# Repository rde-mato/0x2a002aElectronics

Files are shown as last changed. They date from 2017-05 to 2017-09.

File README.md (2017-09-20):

# 0x2a002aElectronics
42 Elec Project - MIDI Sequencer

The 0x2a002a is a MIDI sequencer project. It was part of a school program at 42 Paris (http://www.42.fr/) where most students have limited to none prior experience with electronics, both Firmware and Hardware.

The project spans on a 6 month period, and was carried by Remi de Matos, Théophile Vallée and Laurent Meyer. Each team chooses its own project, and makes it completely from scratch with only one hour of class per week:
* definition of technical specs: user manual, capabilities, parts, consumption.
* design of the electric schemas and routing of the PCB (using Altium software)
* building, soldering, and 3D printing for some parts
* writing asynchronous firmware, without using any external libraries except for the C standard library (including SPI, I2C, UART and chip-specific drivers)
* the only requirement is to use a PIC32 microcontroller.

The result of our project is a fully functional MIDI controller, capable of managing 16 instruments, with each of them 16 patterns of 16 beats.

Watch how Remi is happy about it: https://www.facebook.com/laurent.meyer/posts/10159690303240355

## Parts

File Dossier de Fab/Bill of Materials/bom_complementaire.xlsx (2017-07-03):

Quantity | Designator | Comment | Footprint | Description | Fabricant | RefFabricant | Fournisseur | RefFournisseur | Status
9 | Cod_1, Cod_2, Cod_3, Cod_4, Cod_5, Cod_6, Cod_7, Cod_8, Cod_9 | Cod |  |  | N/A | N/A | N/A | N/A | N/A
1 | P IN | MIDI IN Opt | MIDI | Header, 3-Pin | N/A | N/A | N/A | N/A | N/A
24 | S1_1, S1_2, S2_1, S2_2, S3_1, S3_2, S4_1, S4_2, S5_1, S5_2, S6_1, S6_2, S7_1, S7_2, S8_1, S8_2, S9_1, S9_2, S10_1, S10_2, S11_1, S11_2, S12_1, S12_2 | SW-PB | PAD | Switch | N/A | N/A | N/A | N/A | N/A
1 | P2 | Program / Debug | HDR1X6 | Header, 6-Pin | MOLEX | 22-27-2061 | Farnell | 9731172 | a commander
1 | RP1 | 220 | 3313J-1 | Potentiometer | BOURNS | 3313J-1-221E | Farnell | 2329336 | a commander
1 | P1 | MIDI Out | MIDI | Header, 3-Pin | NEUTRIK | NYS325 | Farnell | 1204611 | a commander
1 | P0 | Power Input | PWR | Header, 2-Pin | SWITCHCRAFT | 712A | Farnell | 1608729 | a commander
1 |  |  |  | Ecrou M3 x100 | DURATOOL | M3- HFA2-S100- | Farnell | 1420788 | a commander
1 |  |  |  | Vis M3 x50 | DURATOOL | D01434 | Farnell | 2444344 | a commander
1 |  |  |  | Vis Fraise M3 x100 | DURATOOL | M310 KRSTMCZ100- | Farnell | 1420398 | a commander
10 |  |  |  | Entretoise Nylon M3 25mm | ETTINGER | 5.30.325 | Farnell | 1336159 | a commander
6 |  |  |  | Entretoise Nylon M3 34mm | DURATOOL | D01492 | Farnell | 1733423 | a commander
14 | C2, C5, C7, C10, C22_MCP1, C22_MCP2, C32, C42, C92, C102, C104, C108, C110, C111 | 100nF | capa 1206 | Capacitor | MULTICOMP | MC1206B104K500CT | Farnell | 1759361 | pas commande ? - available EUR
14 | C3, C8, C21_MCP1, C21_MCP2, C31, C33, C34, C35, C36, C41, C91, C101, C103, C109 | 10uF | capa 1206 | Capacitor | MULTICOMP | MC1206X106K160CT | Farnell | 2320922 | pas commande ? - available EUR
2 | C105, C106 | 22pF | capa 1206 | Capacitor | MULTICOMP | MC1206N220J101CT | Farnell | 2320864 | pas commande ? - available EUR
1 | R1 | 560 | RES 1206 | Resistor | MULTICOMP | MC0125W12065560R | Farnell | 9337490 | pas commande ? - available EUR
1 | R3 | 330 | RES 1206 | Resistor | MULTICOMP | MC0125W12065330R | Farnell | 9337326 | pas commande ? - available EUR
33 | R61, R62, R63, R64, R65, R66, R67, R68, R69, R501_1, R501_2, R502_1, R502_2, R503_1, R503_2, R504_1, R504_2, R505_1, R505_2, R506_1, R506_2, R507_1, R507_2, R508_1, R508_2, R509_1, R509_2, R510_1, R510_2, R511_1, R511_2, R512_1, R512_2 | 39k | RES 1206 | Resistor | MULTICOMP | MC0125W1206539K | Farnell | 9337407 | pas commande ? - available EUR
4 | R2, R4, R101, R102 | 220 | RES 1206 | Resistor | MULTICOMP | MC0125W12065220R | Farnell | 9337210 | pas commande ? - available EUR
43 | R31, R32, R41, R42, R43, R44, R71_1, R71_2, R71_3, R71_4, R71_5, R71_6, R71_7, R71_8, R71_9, R72_1, R72_2, R72_3, R72_4, R72_5, R72_6, R72_7, R72_8, R72_9, R73_1, R73_2, R73_3, R73_4, R73_5, R73_6, R73_7, R73_8, R73_9, R74_1, R74_2, R74_3, R74_4, R74_5, R74_6, R74_7, R74_8, R74_9, R103 | 10K | RES 1206 | Resistor | MULTICOMP | MC0125W1206510K | Farnell | 9337016 | pas commande ? - available EUR
18 | C71_1, C71_2, C71_3, C71_4, C71_5, C71_6, C71_7, C71_8, C71_9, C72_1, C72_2, C72_3, C72_4, C72_5, C72_6, C72_7, C72_8, C72_9 | 10nF | capa 1206 | Capacitor | MULTICOMP | MC1206B103M631CT | Farnell | 1709222 | pas commande ? - available USA
3 | D51_1, D51_2, D61 | BAV20W | Diode SOD-123 | Default Diode | MICRO COMMERCIAL COMPONENTS | BAV20W-TP | Farnell | 1924304 | a commander remplacement 1902417
3 | D51_1, D51_2, D61 | BAV20W | Diode SOD-123 | Default Diode | DIODES INC. | BAV20W | Farnell | 1902417 | annule - attente livraison
32 | D1_1, D1_2, D1_3, D1_4, D2_1, D2_2, D2_3, D2_4, D3_1, D3_2, D3_3, D3_4, D4_1, D4_2, D4_3, D4_4, D5_1, D5_2, D5_3, D5_4, D6_1, D6_2, D6_3, D6_4, D7_1, D7_2, D7_3, D7_4, D8_1, D8_2, D8_3, D8_4 | LED | LED-3mm | LED, ROUND, 5MM, BLUE | CREE | C503B-BCN-CV0Z0462 | Farnell | 2414443 | pas commande ? - available USA
1 | P3 | SDAMB-01215BT00 |  |  | MULTICOMP | SDAMB-01215BT00 | Farnell | 9186140 | recu
1 | RP2 | 100 | 3313J-1 | Potentiometer | BOURNS | 3313J-1-101E | Farnell | 2321829 | recu
1 | RP91 | 10K | 3313J-1 | Potentiometer | BOURNS | 3313J-1-103E | Farnell | 1612588 | recu
1 | C107 | 10uF | CAPA 1206 POL | Polarized Capacitor (Radial) | KEMET | T491A106K010AT | Farnell | 1457413 | recu
2 | C1, C6 | 470uF | CAPA PANA SIZE D* | Polarized Capacitor (Radial) | PANASONIC | EEEFTA471XAP | Farnell | 2065963 | recu
2 | C4, C9 | 100uF | CAPA PANA SIZE D* | Polarized Capacitor (Radial) | PANASONIC | EEE1AA101SP | Farnell | 2326098 | recu
2 | U7, U8 | LM317 | D2PAK |  | ON SEMICONDUCTOR | LM317D2T-TR | Farnell | 1564300 | recu
4 | D2, D3, D6, D7 | GF1B | DO-214AC(SMA) | Default Diode | FAIRCHILD SEMICONDUCTOR | GF1B | Farnell | 1467477 | recu
1 | Y1 | 8Mhz | HC49/4H SMX CRYSTAL | Crystal Oscillator | FOX ELECTRONICS | FOXSDLF/080-20 | Farnell | 2063972 | recu
1 | U4 | HT16K33 | HT16K33 SOP |  | Holtek | HT16K33-28SOP | AliExpress | N/A | recu
1 | U6 | LCD-128H064A | LCD-128H064A |  | N/A | KS0108 | Adafruit | 188 | recu
2 | U3_MCP1, U3_MCP2 | MCP23S17 | MCP23S17-E/SO |  | Microchip | MCP23S17-E/SO | Farnell | 1332093 | recu
1 | U2 | NL37WZ07USG | NL37WZ07USG |  | ON SEMICONDUCTOR | NL37WZ07USG | Farnell | 2534491 | recu
1 | Cod_9 | Switch | PEC11R-4xxxF-Sxxxx |  | BOURNS | PEC11R-4220F-S0024 | Farnell | 2663527 | recu
8 | Cod_1, Cod_2, Cod_3, Cod_4, Cod_5, Cod_6, Cod_7, Cod_8 | Switch | PEC11R-4xxxF-Sxxxx |  | BOURNS | PEC11R-4020F-S0024 | Farnell | 2663519 | recu
1 | U1 | PIC32MX150F128B | PIC32MX150F128B-I/SO |  | Microchip | PIC32MX150F128B-I/SO | Farnell | 2313766 | recu
3 | D1, D4, D5 | RS3B+ | SMC Vishay | Default Diode | MULTICOMP | RS3B+ | Farnell | 2675034RL | recu
1 | U5 | SST25VF020B | SST25VF020B |  | MICROCHIP | SST25VF020B-80-4I-SAE | Farnell | 1829953 | recu

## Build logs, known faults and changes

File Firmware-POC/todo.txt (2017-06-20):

- cleaner le code a perimetre egal
- faire un systeme de definition de keys
- faire un fichier avec toutes les variables globales ?
- mettre en place le mode rec
- voir si on ne peut pas simplifier le SPI en ne faisant que du 8 bits
- optimiser l'affichage de l'écran (changer uniquement les chars qui changent)
- gerer le multislave du spi

determiner des boutons de controle (pas dans le chenillard) et les actions associees
mettre des patterns en memoire
faire marcher le lcd
garder en memoire les valeurs des parametres
comment sauvegarder d'une session a l'autre meme en cas de machine eteinte a la main ?
comment faire durer un message a l'écran pendant x secondes seulement ? il nous faut un timer disponible. Ou faire une fonction de timer generique, qui prend un callback. Ca permettrait de gerer aussi les appuis longs.
dedoubler le charset pour faire la diapositive de chaque caractere
determiner des ecrans type pour chaque situation, qui prennent en parametre les variables globales : ex : un encodeur tourne etc
par consequent, bien s'assurer qu'un refresh de l'écran est instant, et qu'en plus il ne bouffe pas toutes les ressources du PIC ce qui serait bloquant

SPI
besoin de faire un buffer
comment mettre en place un systeme de priorité dans le buffer ?
d'ailleurs qu'est ce qui est prioritaire pour le spi ? ecran ou encodeurs ou ???
gerer l'envoi des données avec un buffer par slave ?
possible de gérer les 32 en 4 fois 8 bits ? quel impact ?
besoin de gerer : un mcp pour lcd, un mcp pour encodeurs, une flash, une sd

Variables :
- note courante (reinitialisee a chaque demarrage de machine). Note au sein de l'octave, donc la valeur finale entre 12 et 108 peut etre recuperee facilement
- velocite courante
- octave courant
- instrument courant
- boucle courante
- tempo
- 8 parametres additionnels par instrument
- play/pause
- instruments actifs => u16
- mode courant : play / live

ORDRE DE LA MEMOIRE
Instrument
Pattern
Beat
Notes et velocites

BESOINS EN TIMERS
- bpm
- appui long
- ecrans temporaires

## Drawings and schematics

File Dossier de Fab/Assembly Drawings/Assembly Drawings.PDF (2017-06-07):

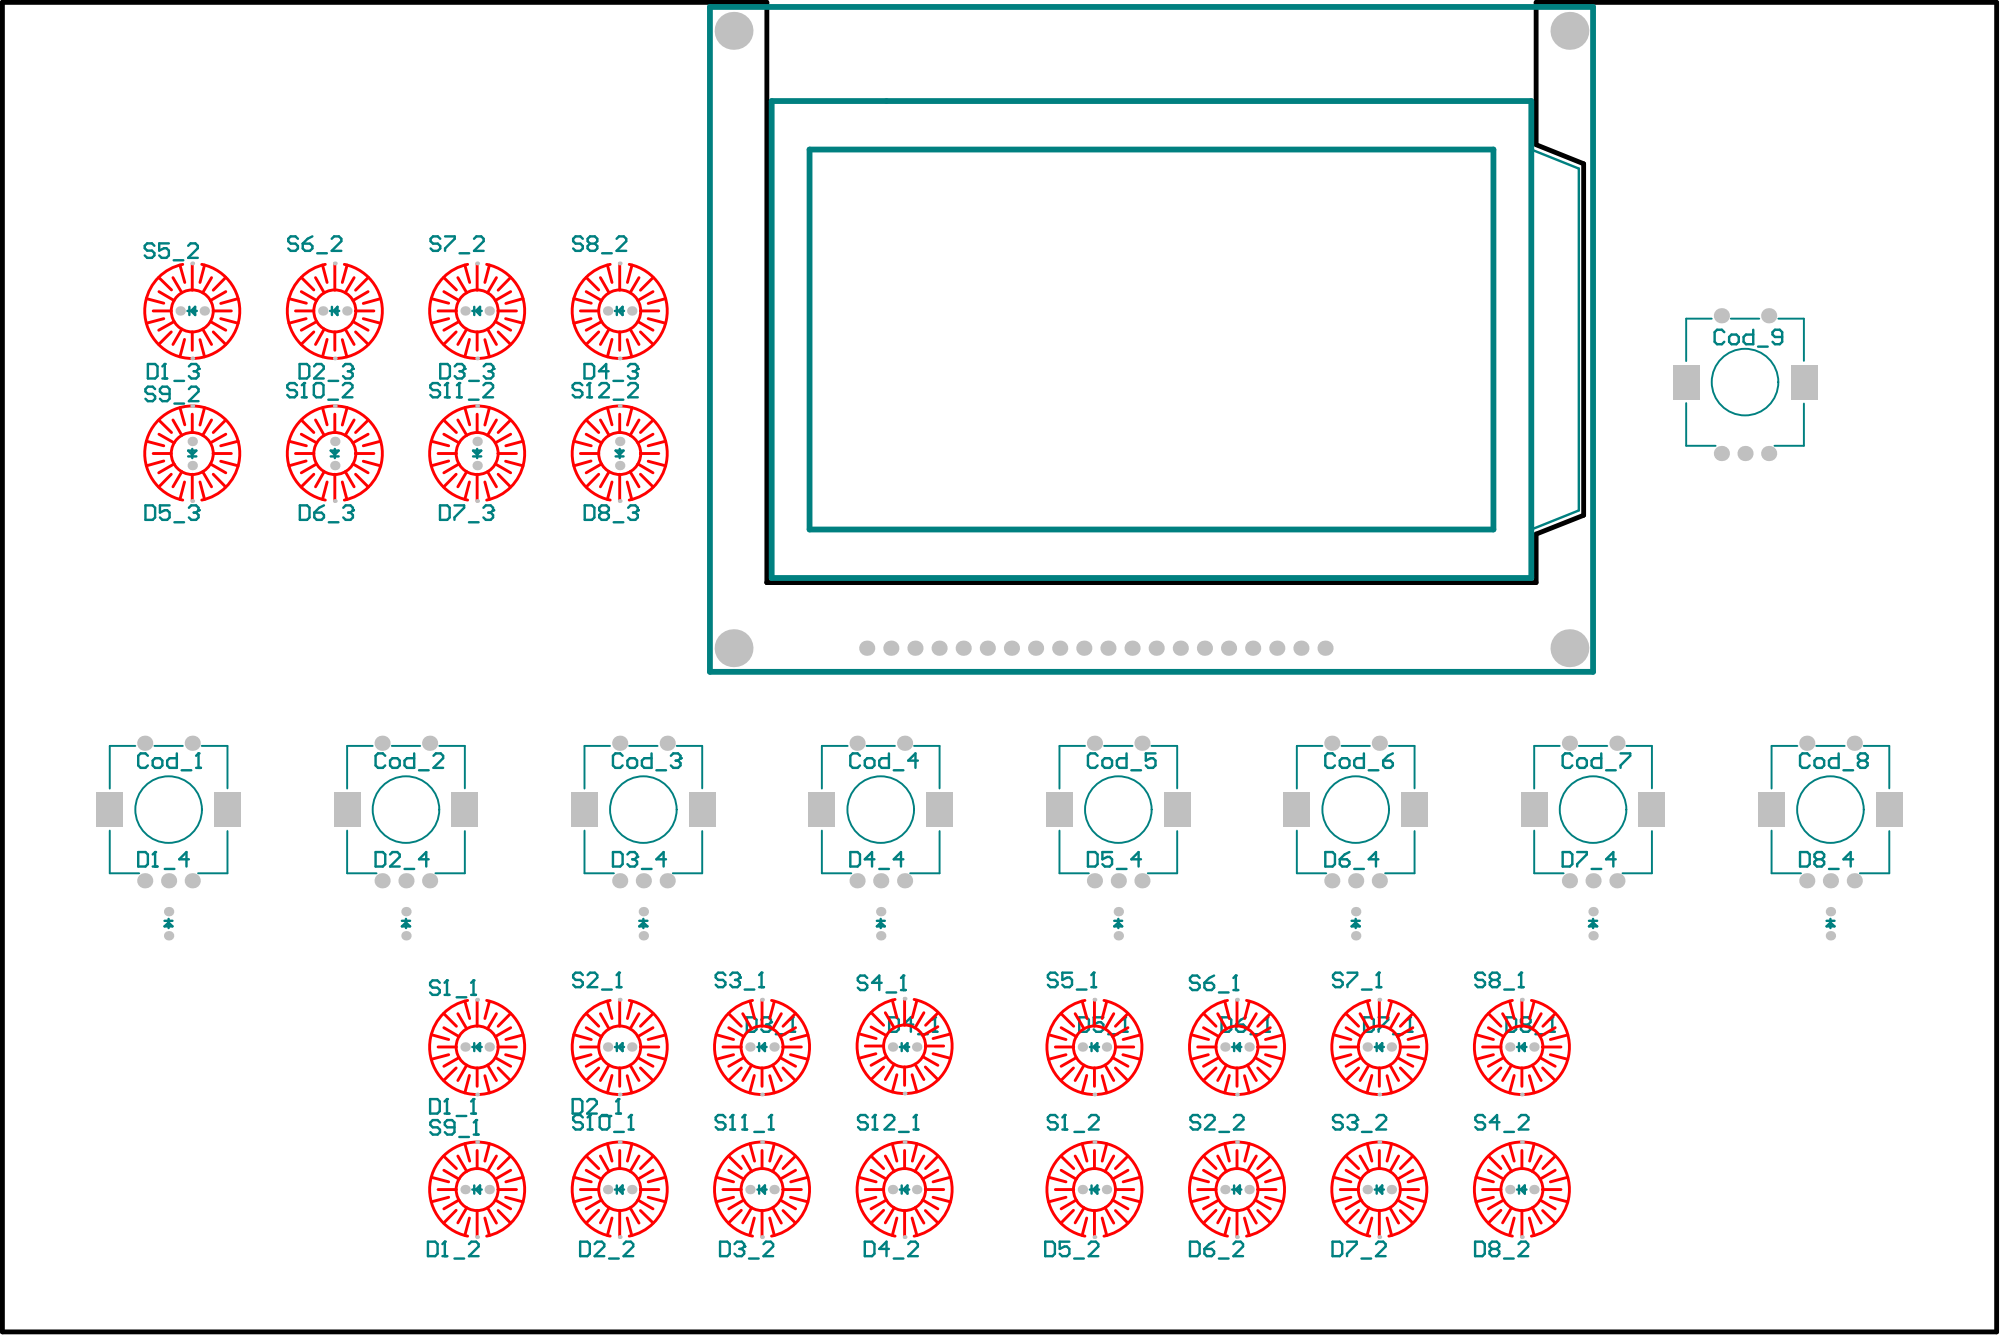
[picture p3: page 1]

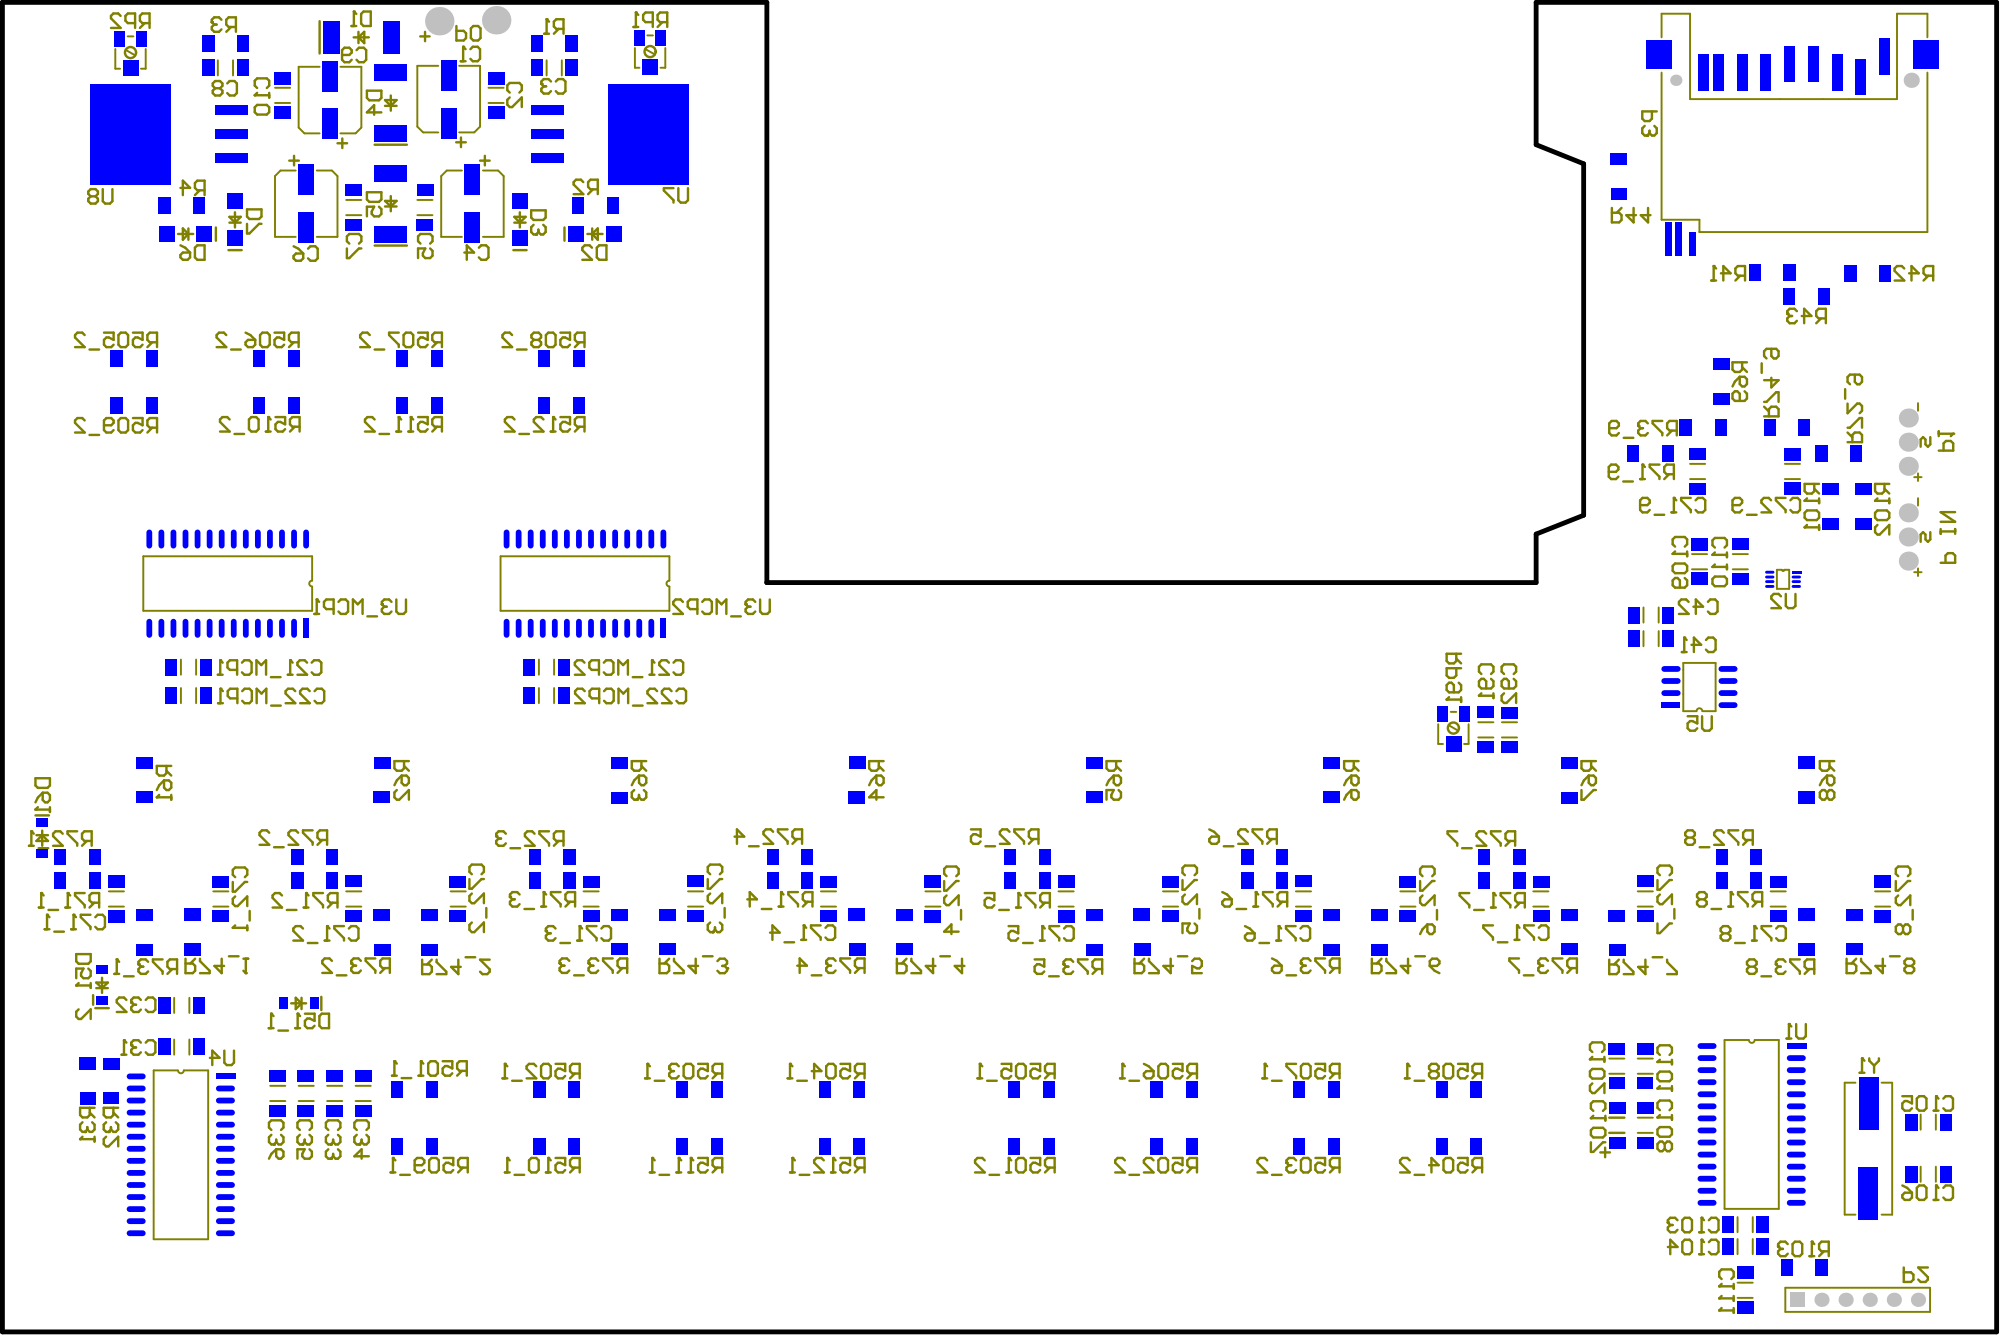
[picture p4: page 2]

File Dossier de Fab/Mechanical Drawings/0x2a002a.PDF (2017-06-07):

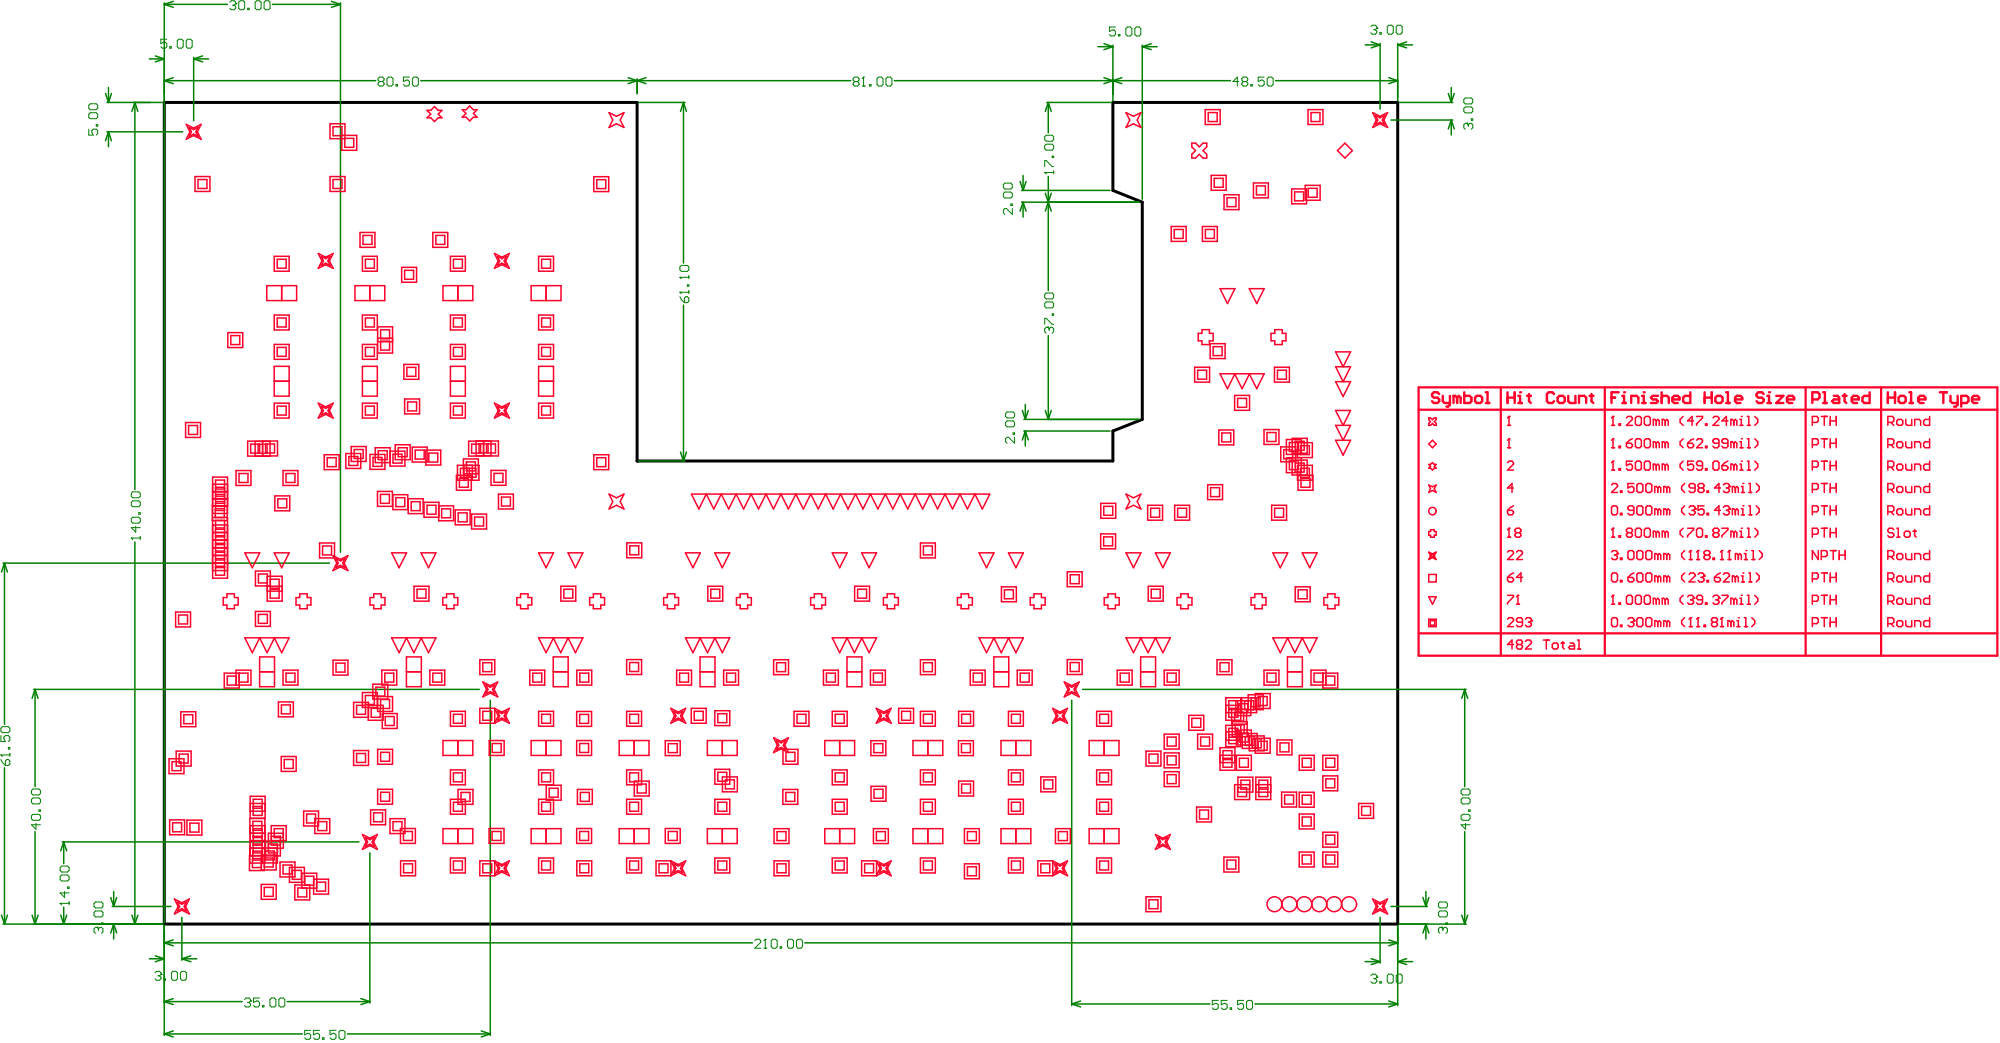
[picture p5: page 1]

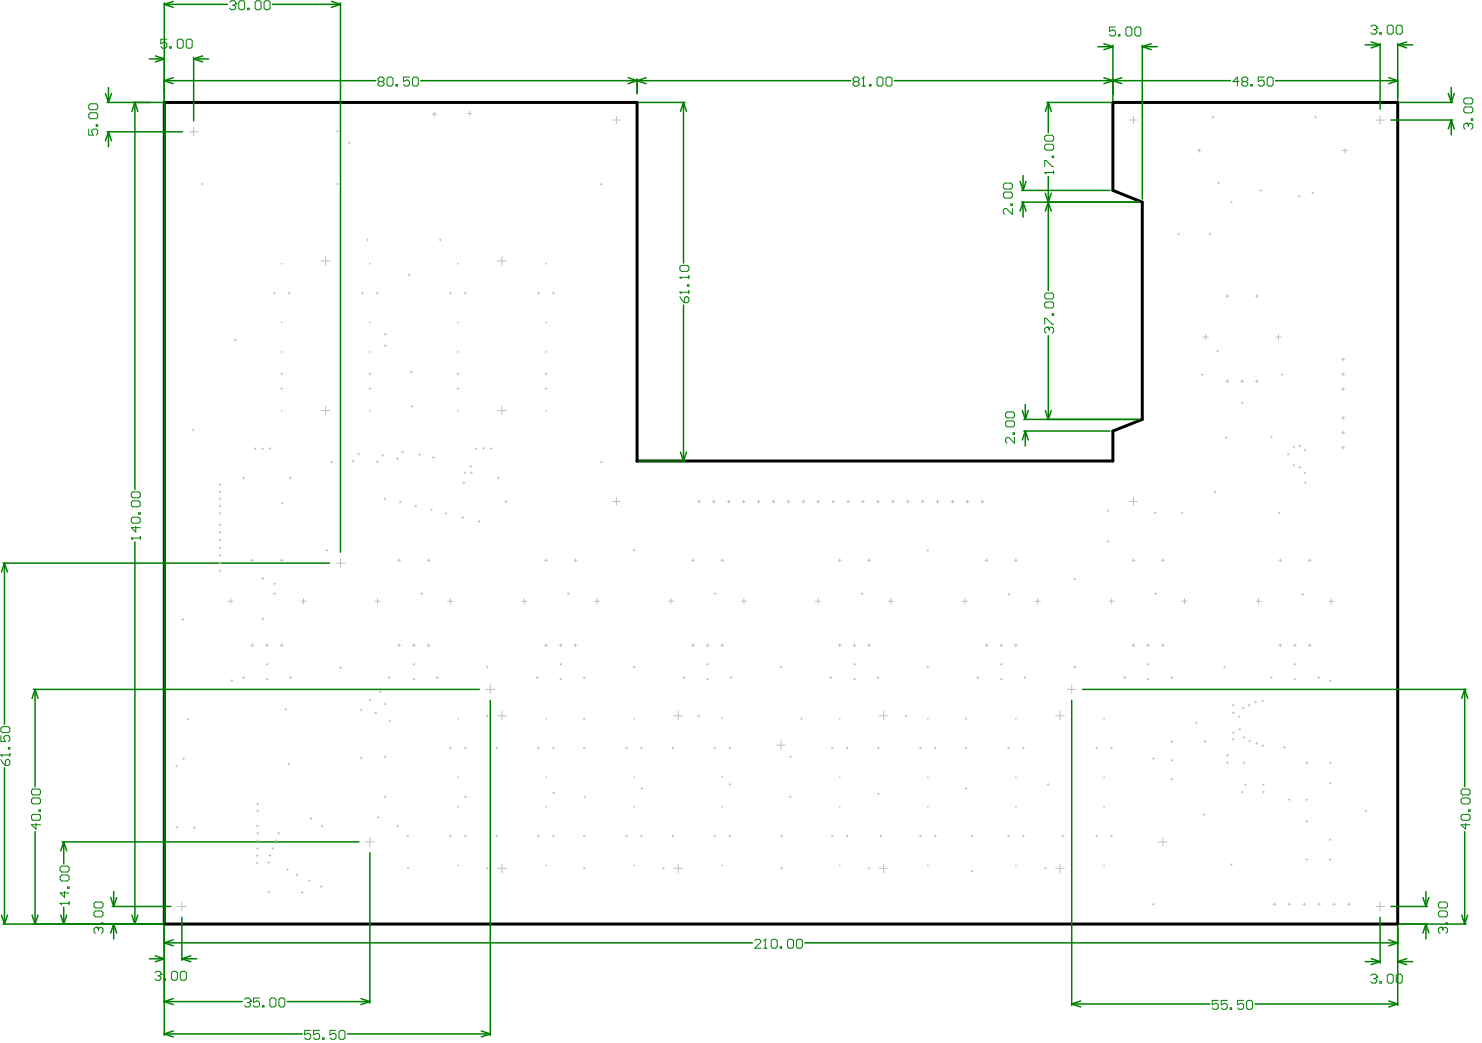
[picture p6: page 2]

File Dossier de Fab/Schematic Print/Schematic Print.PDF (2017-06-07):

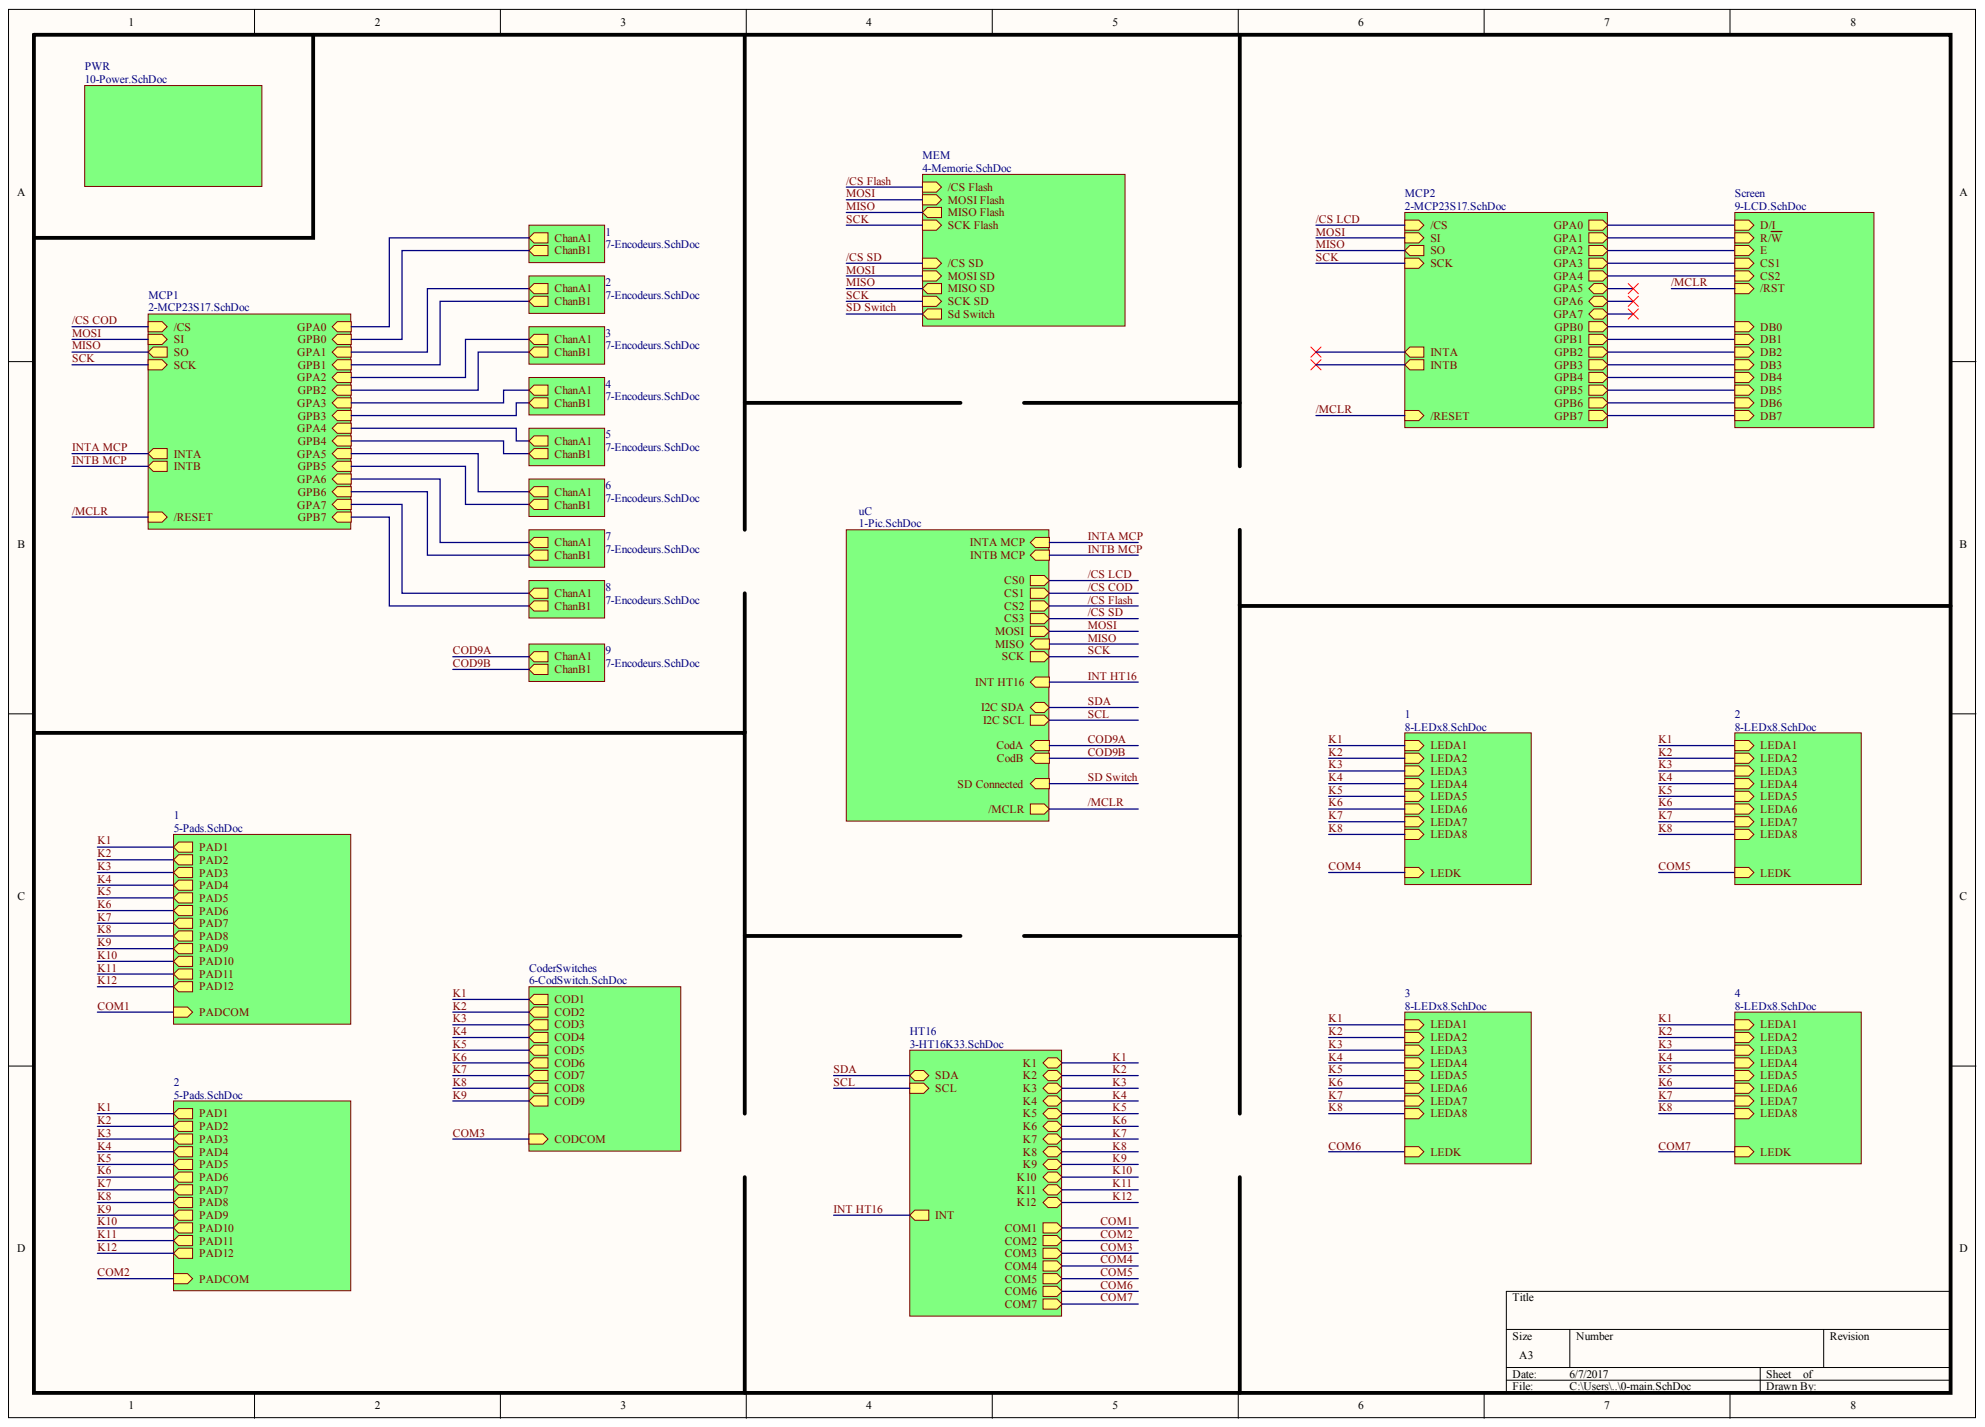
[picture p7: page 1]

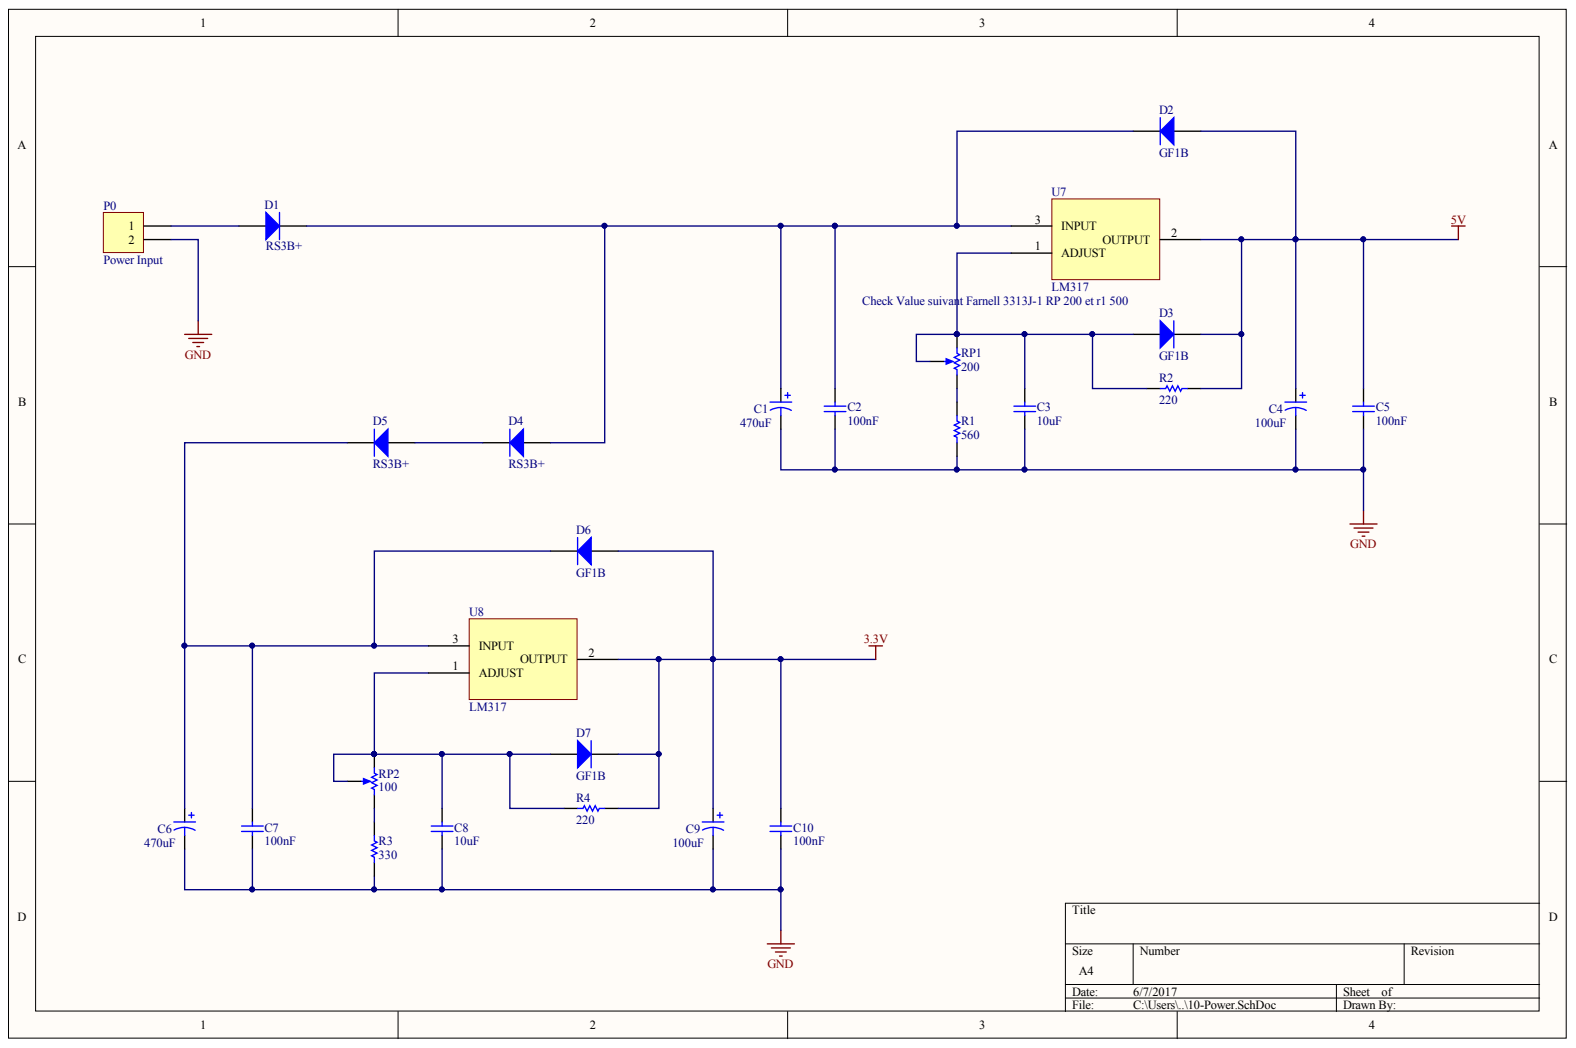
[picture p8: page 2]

Check Value suivant Farnell 3313J-1 RP 200 et r1 500

Size A4 | Number | Revision

Date: 6/7/2017 | Sheet of
File: C:\Users\..\10-Power.SchDoc | Drawn By:

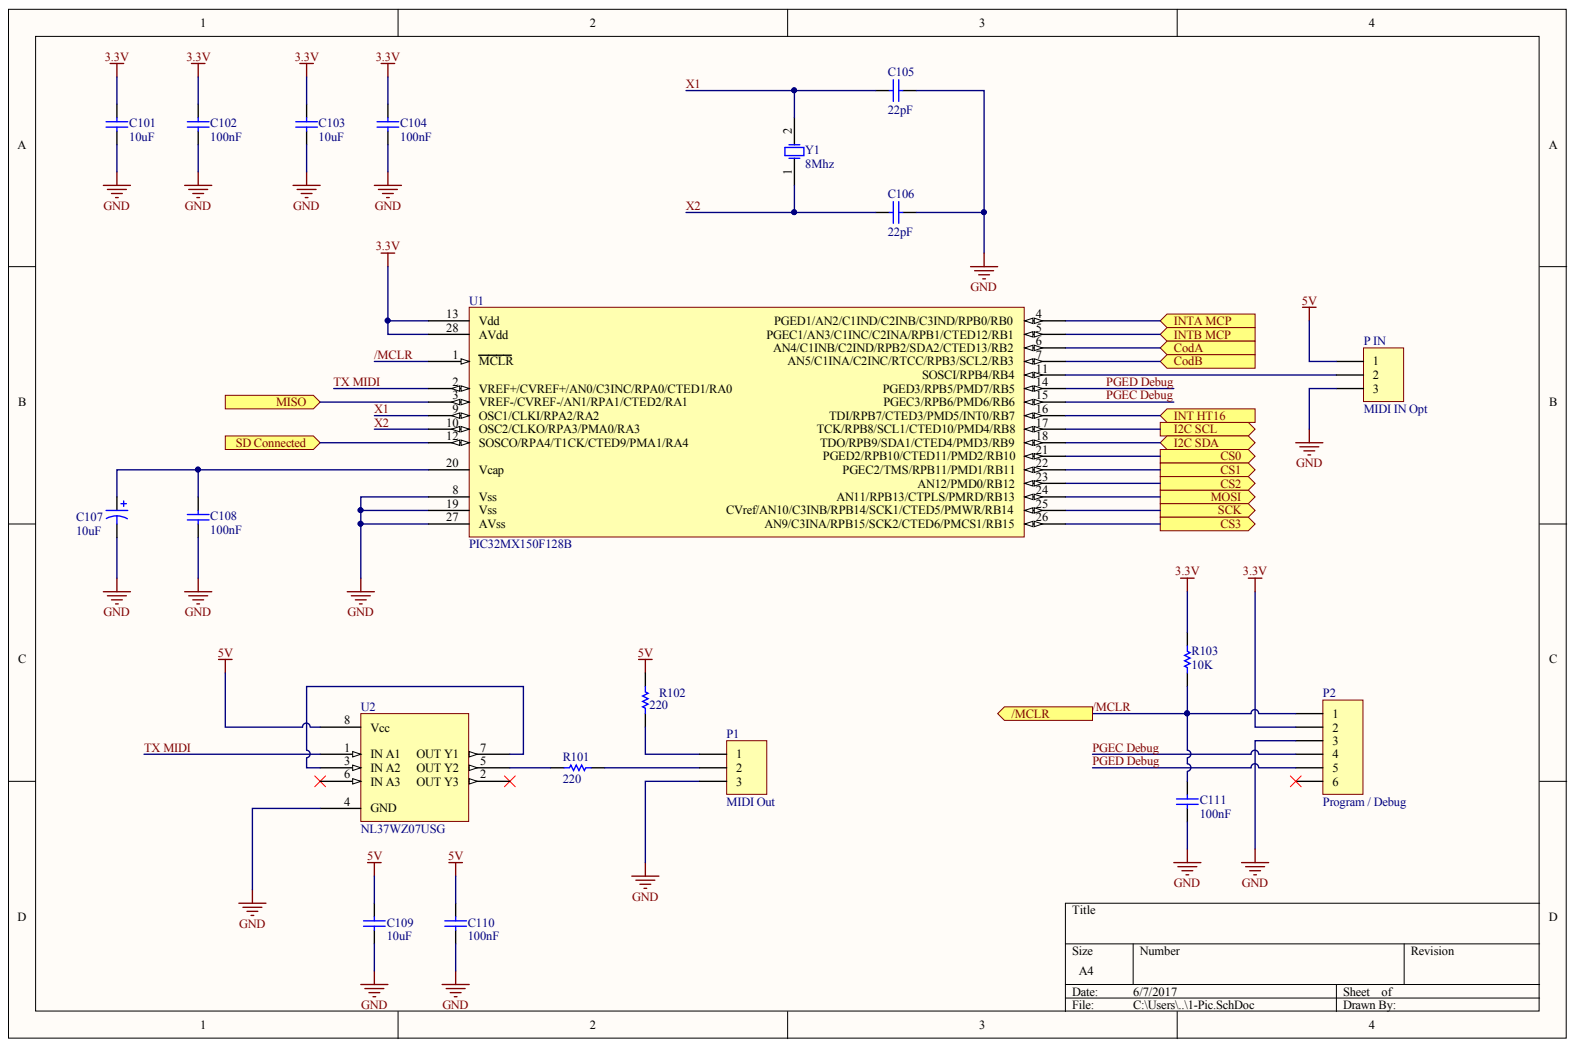
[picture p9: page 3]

Vss 8

AVss 27

Size A4 | Number | Revision

Date: 6/7/2017 | Sheet of
File: C:\Users\..\1-Pic.SchDoc | Drawn By:

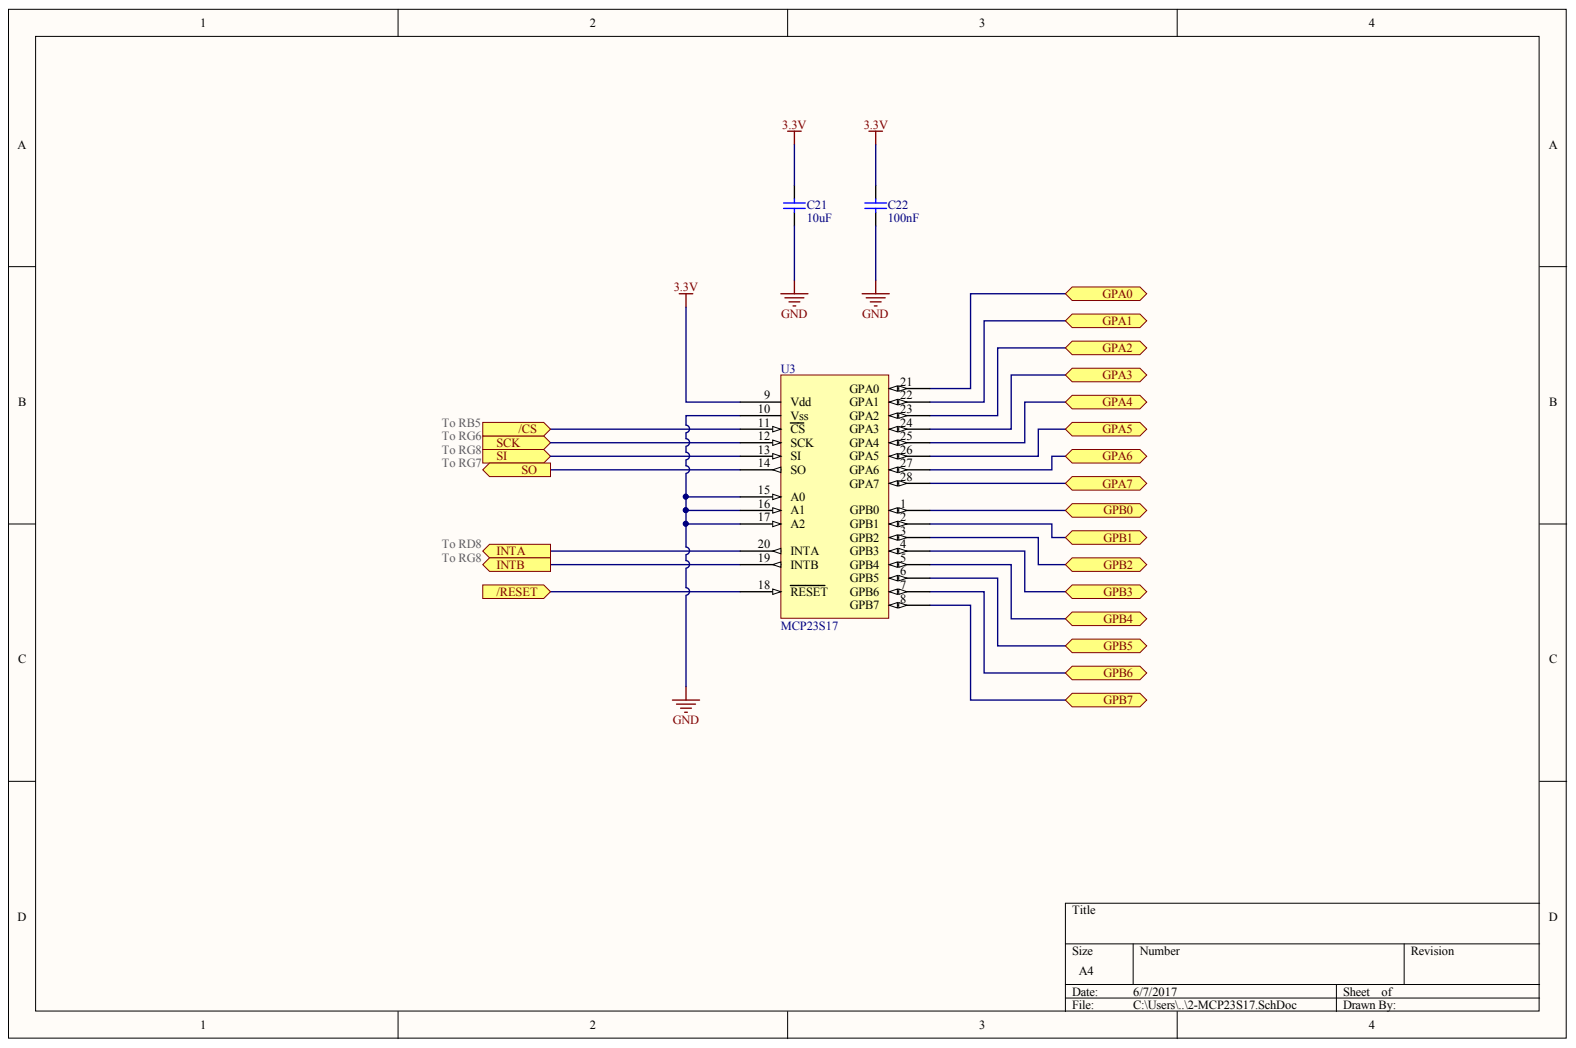
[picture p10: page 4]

Numbe r | R evision

: 6/7/2017 | She et of
File : C:\Use rs\. .\2-MC P23S17. S chDoc | D r awn By:

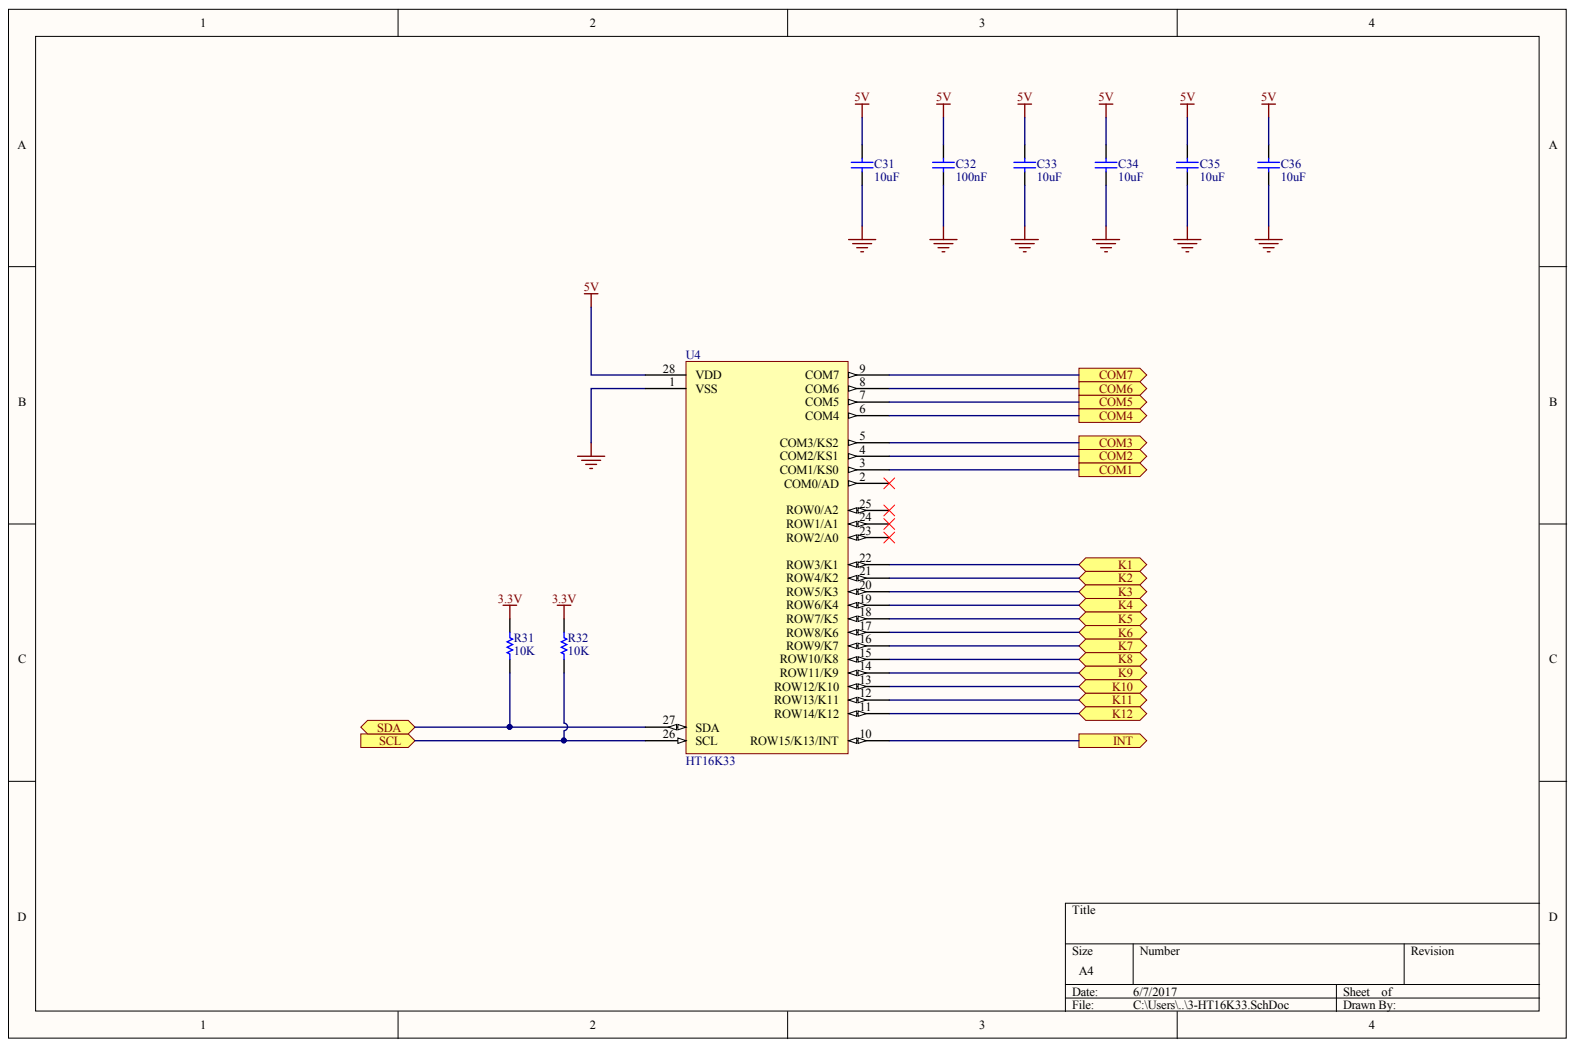
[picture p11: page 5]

Numbe r | R evision

: 6/7/2017 | She et of
File : C:\Use rs\. .\3-HT16K33. S chDoc | D r awn By:

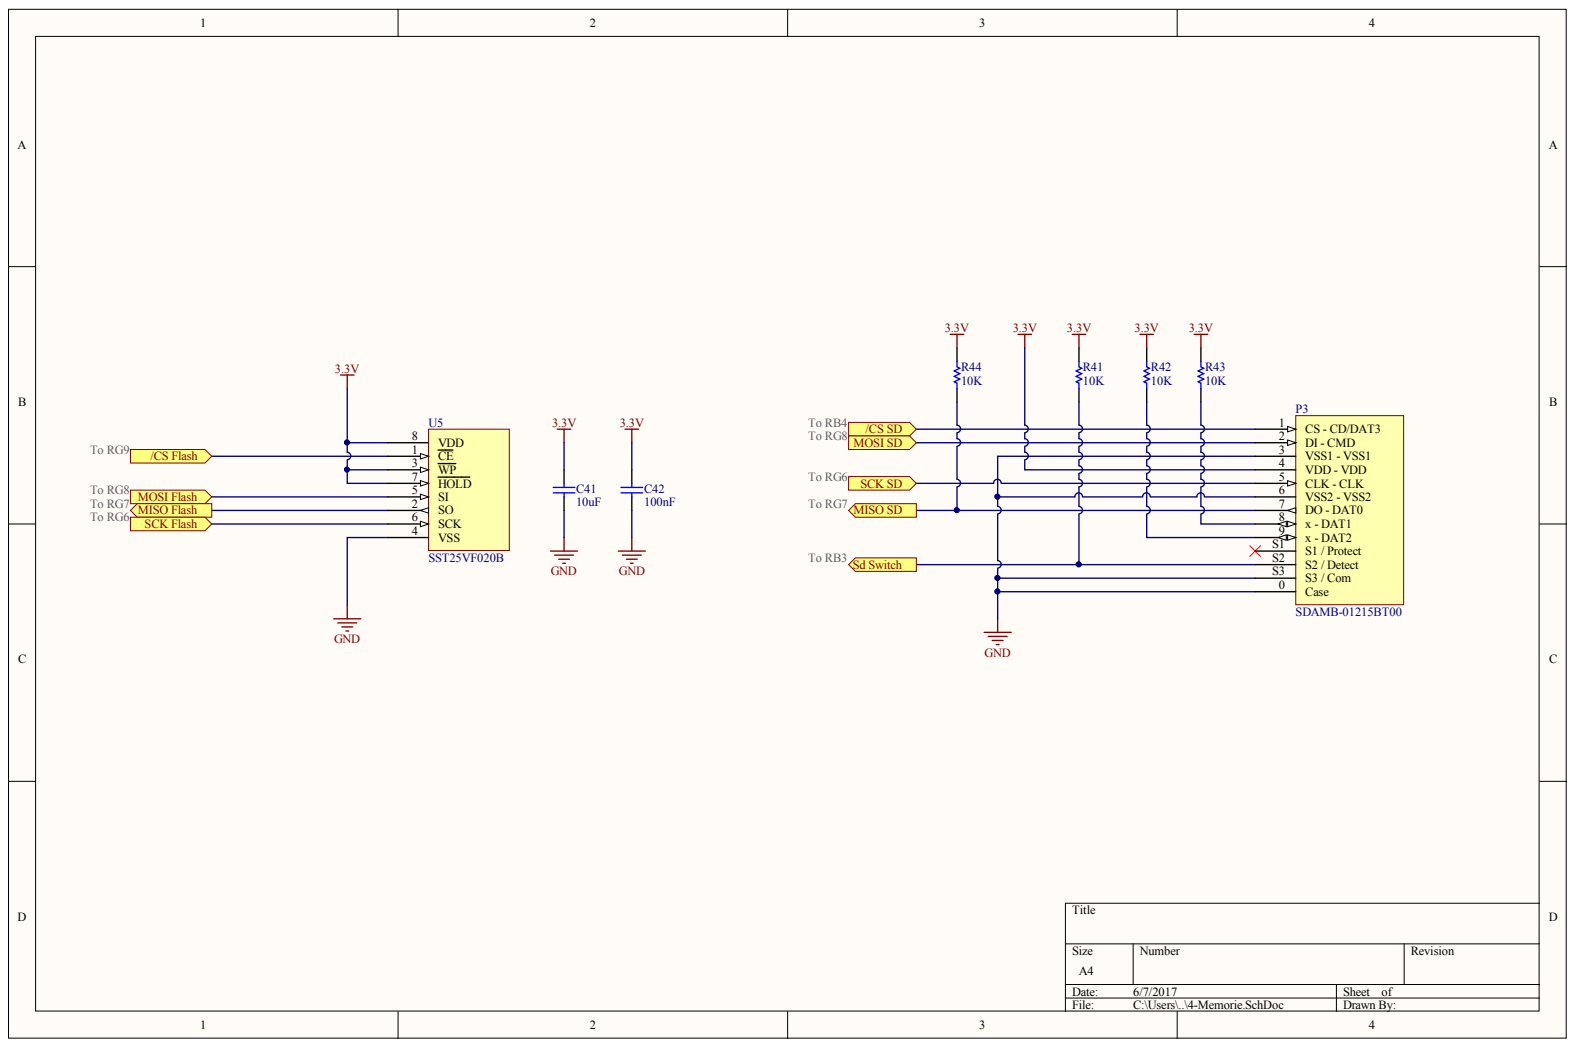
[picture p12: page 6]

Numbe r | R evision

: 6/7/2017 | She et of
File : C:\Use rs\. .\4-Memorie . S chDoc | D r awn By:

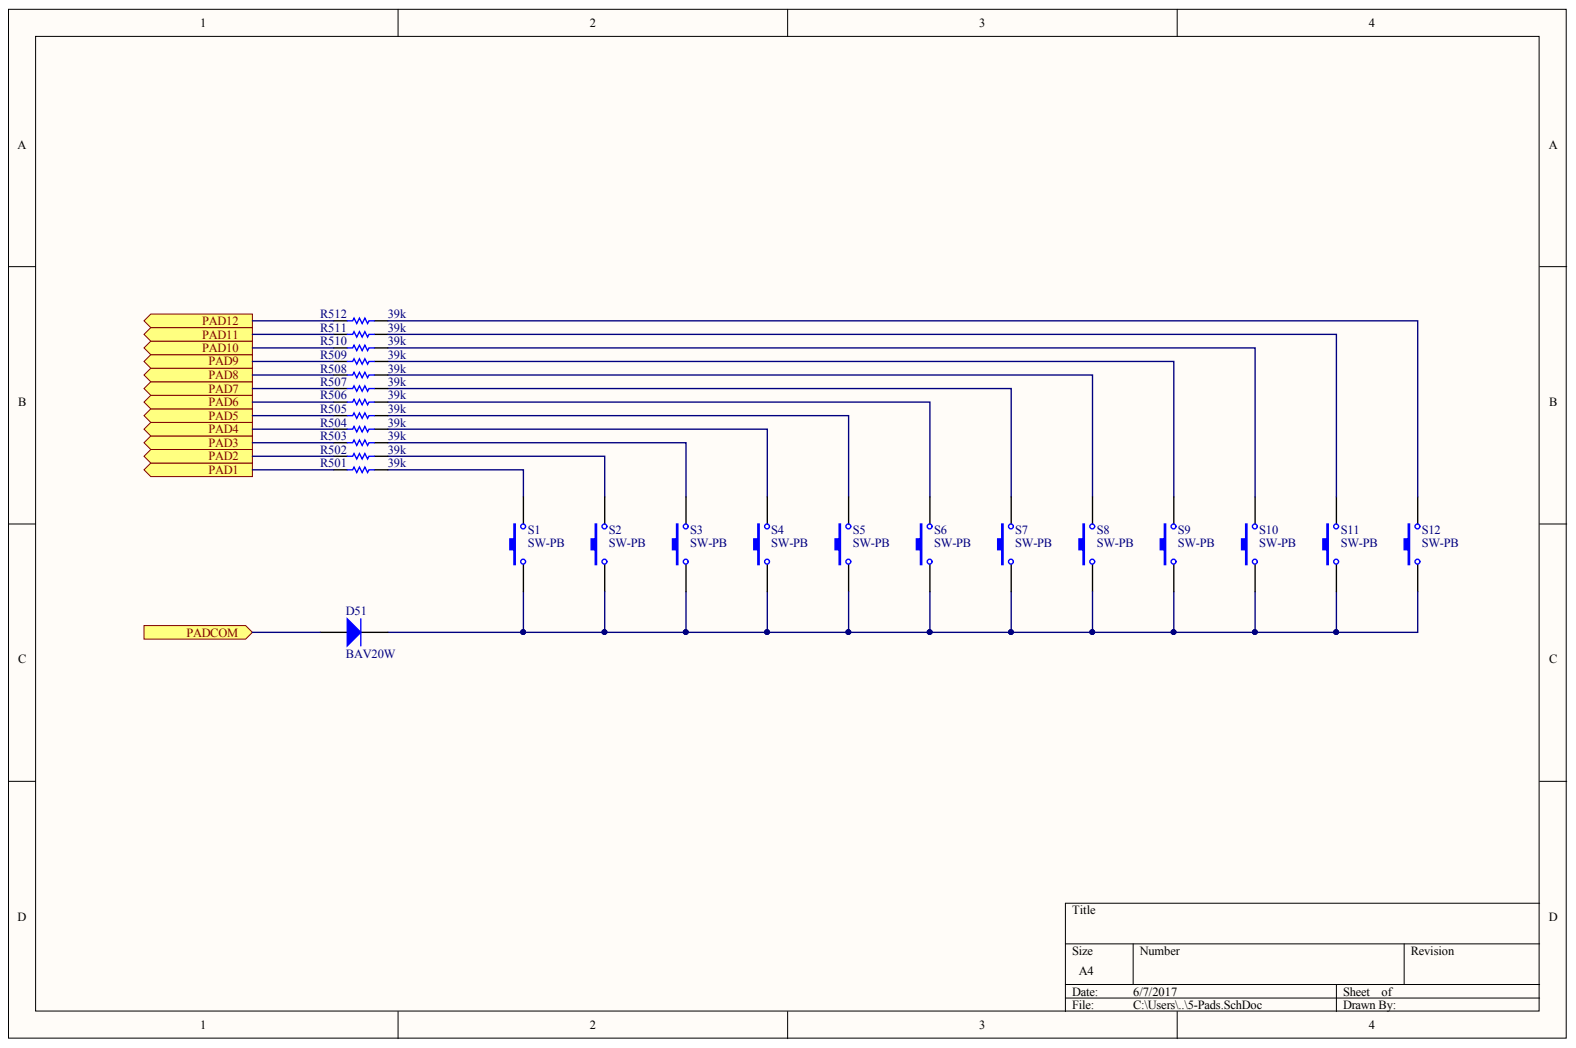
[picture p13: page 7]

Numbe r | R evision

: 6/7/2017 | She et of
File : C:\Use rs\. .\5-P ads. S chDoc | D r awn By:

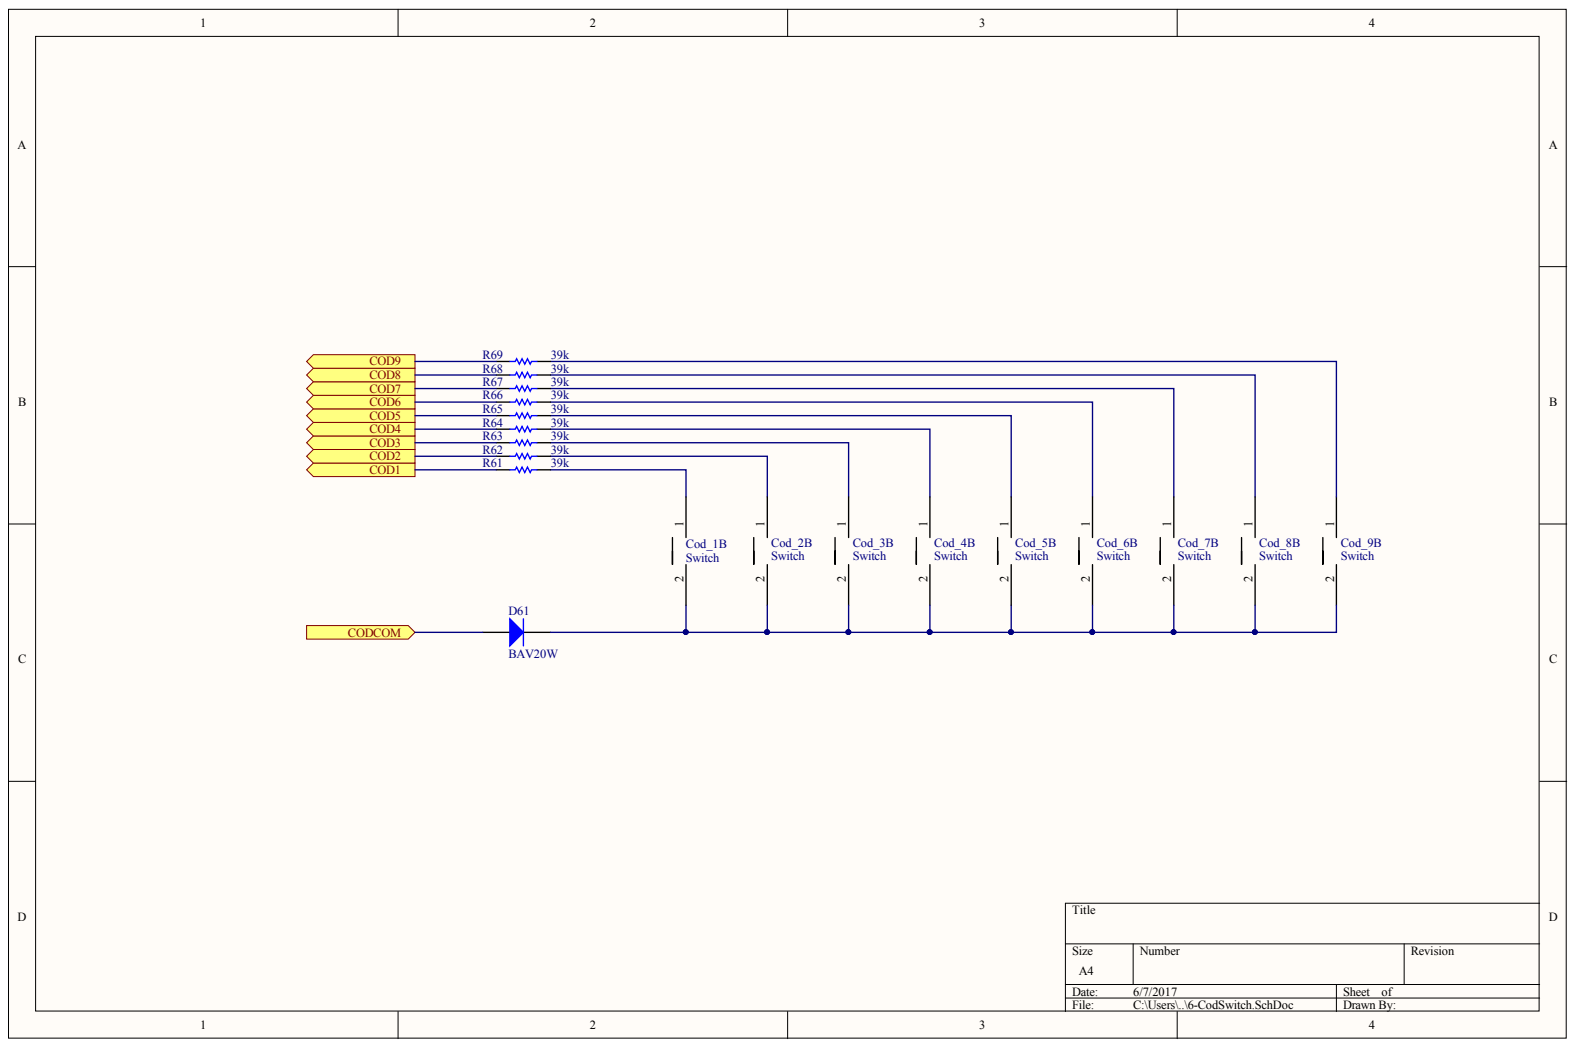
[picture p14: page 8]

Numbe r | R evision

: 6/7/2017 | She et of
File : C:\Use rs\. .\6-CodS witch. S chDoc | D r awn By:


Size A4 | Number | Revision

Date: 6/7/2017 | Sheet of
File: C:\Users\..\7-Encodeurs.SchDoc | Drawn By:


Numbe r | R evision

: 6/7/2017 | She et of
File : C:\Use rs\. .\8-LEDx8. S chDoc | D r awn By:


Size A4 | Number | Revision

Date: 6/7/2017 | Sheet of
File: C:\Users\..\9-LCD.SchDoc | Drawn By:

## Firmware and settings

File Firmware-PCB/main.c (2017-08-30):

#include <xc.h>
#include <sys/attribs.h>
#include "0x2a002a.h"

struct s_all	all;

int	main(void)
{
	init_all_struct();
	GPIO_and_PPS_init();
	TIMER_init();
	I2C1_init();
	SPI1_init();

	MCP_LCD_init();
	LCD_init();
	MCP_ENCODERS_init_blocking();
	UART1_init();
	initial_eeprom_download();
	request_template(TEMPLATE_DEFAULT);
	set_bpm();

	INT_init();
	HT16_init();
	IFS0bits.INT1IF = 1; // a garder pour reset les encoders
	TIMER2_ON;

	while (42)
	{
		I2C1_manager();
		SPI1_priority_manager();
		CLEAR_WATCHDOG;
	}
	return (0);
}

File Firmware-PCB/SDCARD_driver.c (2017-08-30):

#include <xc.h>
#include <sys/attribs.h>
#include "0x2a002a.h"


static u32				SD_return;
static u8				SD_error = 0;
static u8				SD_type = SD_SDSC;
static u32				SD_block_number = 0;
static u16				SD_rw_length;
static u16				SD_rw_index = 0;
static u8 			  	*SD_rw_ptr;
static generic_callback	SD_rw_callback = NULL;

void	send_lots_clk(void)
{
	u32	read32;
	u8	i = 20;

	SPI1CONbits.MODE32 = 1;
	while (--i)
	{
		SPI1BUF = 0xFFFFFFFF;
		while (SPI1STATbits.SPIBUSY) ;
		read32 = SPI1BUF;
	}
	SPI1CONbits.MODE32 = 0;
}

u8	SD_command_retry(u8 cmd, u32 arg, u8 crc, u8 restype)
{
	u8	read8;
	u32	read32;
	u8	ret = 0xFF;
	u32	retries = SD_RETRIES;

	CS_SD = 0x0;
	SPI1BUF = 0x40 | cmd;
	while (SPI1STATbits.SPIBUSY) ;
	read8 = SPI1BUF;

	SPI1CONbits.MODE32 = 1;

	SPI1BUF = arg;
	while (SPI1STATbits.SPIBUSY) ;
	read32 = SPI1BUF;

	SPI1CONbits.MODE32 = 0;

	SPI1BUF = crc;
	while (SPI1STATbits.SPIBUSY) ;
	read8 = SPI1BUF;

	while (retries--)
	{
		SPI1BUF = 0xFF;
		while (SPI1STATbits.SPIBUSY) ;
		if ((ret = SPI1BUF) != 0xFF)
			break;
	}
	if (ret != 0xFF && (restype == SD_R3 || restype == SD_R7))
	{
		SPI1CONbits.MODE32 = 1;
		SPI1BUF = 0xFFFFFFFF;
		while (SPI1STATbits.SPIBUSY) ;
		SD_return = SPI1BUF;
		SPI1CONbits.MODE32 = 0;
	}

	CS_SD = 0x1;
	SPI1BUF = 0xFF;
	while (SPI1STATbits.SPIBUSY) ;
	read8 = SPI1BUF;
	return (ret);
}

u8	SD_card_init(void)
{
	u8	R1_response;
	u32	retries = SD_RETRIES;
	u8 ret = 0;

	SPI1BRG = 3; //divise la frequence de SCK par 6 = 2 * (2 + 1)
	send_lots_clk();
	R1_response = SD_command_retry(0, 0x0, 0x95, SD_R1);
	R1_response = SD_command_retry(8, 0x1AA, 0x87, SD_R7);
	R1_response = SD_command_retry(58, 0x0, 0x01, SD_R3); // reads the OCR register to know the voltage and therefore if the card is SDSC, SDHC or SDXC

	while (retries--)
	{
		R1_response = SD_command_retry(55, 0x0, 0x65, SD_R1);
		R1_response = SD_command_retry(41, 0x0, 0xE5, SD_R1);
		if (R1_response == 0x00)
			break;
	}
	if (R1_response == 0x00)
		ret = 1;
	R1_response = SD_command_retry(58, 0x0, 0x01, SD_R3); // reads the OCR register, if bit 30 of OCR is 0 then SDSC else SDHC or SDXC
	if (SD_return & (1 << 30))
		SD_type = SD_SDHC;
	R1_response = SD_command_retry(16, SD_BLOCK_SIZE, 0x01, SD_R1); // set block length to 512
	SPI1BRG = 0; //set baudrate 1Mhz suivant 8 Mhz du pbclk
	return (ret);
}

void	SM_SD_read_block_callback(void)
{
	static u8	state = E_SPI1_SDCARD_READ_INIT;
	u8 			read8;
	u32			read32;
	static u32		retries;

	if (!SD_IS_PRESENT)
	{
		read8 = SPI1BUF;
		SPI1_release();
		state = E_SPI1_SDCARD_READ_INIT;
		SD_rw_index = 0;
		SPI1Fbits.SD_r = 0;
		request_template(TEMPLATE_SD_ERROR);
		CS_SD = CS_LINE_UP;
	}

	switch (state)
	{
		case E_SPI1_SDCARD_READ_INIT:
			read8 = SPI1BUF;
			CS_SD = CS_LINE_DOWN;
			SPI1BUF = SD_CMD_READ_SINGLE_BLOCK;
			state = E_SPI1_SDCARD_READ_SEND_BLOCK_ADDRESS;
			SPI1_TRANSMIT_ENABLE = INT_ENABLED;
			break;

		case E_SPI1_SDCARD_READ_SEND_BLOCK_ADDRESS:
			read8 = SPI1BUF;
			SPI1CONbits.MODE32 = 1;
			if (SD_type == SD_SDSC)
				SD_block_number *= SD_BLOCK_SIZE;
			SPI1BUF = SD_block_number;
			state = E_SPI1_SDCARD_READ_SEND_DUMMY_CRC_AND_START_RETRIES;
			SPI1_TRANSMIT_ENABLE = INT_ENABLED;
			break;

		case E_SPI1_SDCARD_READ_SEND_DUMMY_CRC_AND_START_RETRIES:
			read32 = SPI1BUF;
			SPI1CONbits.MODE32 = 0;
			SPI1BUF = SD_CMD_DUMMY_CRC;
			retries = SD_RETRIES;
			state = E_SPI1_SDCARD_READ_RETRY_TILL_NOT_BUSY;
			SPI1_TRANSMIT_ENABLE = INT_ENABLED;
			break;

		case E_SPI1_SDCARD_READ_RETRY_TILL_NOT_BUSY:
			read8 = SPI1BUF;
			if (read8 == 0x00)
			{
				retries = SD_RETRIES;
				state = E_SPI1_SDCARD_READ_RETRY_TILL_TOKEN;
				SPI1BUF = 0xFF;
			}
			else if (retries)
			{
				SPI1BUF = 0xFF;
				retries--;
			}
			else
			{
				state = E_SPI1_SDCARD_READ_ERROR;
				SD_error = SD_READ_ERROR_TOO_MANY_RETRIES;
			}
			SPI1_TRANSMIT_ENABLE = INT_ENABLED;
			break;

		case E_SPI1_SDCARD_READ_RETRY_TILL_TOKEN:
			read8 = SPI1BUF;
			if (read8 != 0xFF)
			{
				if (read8 == 0b11111110)
				{
					state = E_SPI1_SDCARD_READ_GET_ONE_BYTE;
					SPI1BUF = 0xFF;
				}
				else
				{
					state = E_SPI1_SDCARD_READ_ERROR;
					SD_error = SD_READ_ERROR_WRONG_TOKEN ;
				}
			}
			else if (retries)
			{
				SPI1BUF = 0xFF;
				retries--;
			}
			else
			{
				state = E_SPI1_SDCARD_READ_ERROR;
				SD_error = SD_READ_ERROR_TOO_MANY_RETRIES;
			}
			SPI1_TRANSMIT_ENABLE = INT_ENABLED;
			break;

		case E_SPI1_SDCARD_READ_GET_ONE_BYTE:
			read8 = SPI1BUF;
			if (SD_rw_index >= SD_BLOCK_SIZE || SD_rw_index >= SD_rw_length)
				state = E_SPI1_SDCARD_READ_SEND_FINAL_FFS_1;
			else
				SD_rw_ptr[SD_rw_index++] = read8;
			SPI1BUF = 0xFF;
			SPI1_TRANSMIT_ENABLE = INT_ENABLED;
			break;

		case E_SPI1_SDCARD_READ_SEND_FINAL_FFS_1:
			read8 = SPI1BUF;
			SPI1BUF = 0xFF;
			state = E_SPI1_SDCARD_READ_SEND_FINAL_FFS_2;
			SPI1_TRANSMIT_ENABLE = INT_ENABLED;
			break;

		case E_SPI1_SDCARD_READ_SEND_FINAL_FFS_2:
			read8 = SPI1BUF;
			SPI1BUF = 0xFF;
			state = E_SPI1_SDCARD_READ_RELASE;
			SPI1_TRANSMIT_ENABLE = INT_ENABLED;
			break;

		case E_SPI1_SDCARD_READ_RELASE:
			read8 = SPI1BUF;
			CS_SD = CS_LINE_UP;
			SPI1BUF = 0xFF;
			state = E_SPI1_SDCARD_READ_LAST_FF;
			SPI1_TRANSMIT_ENABLE = INT_ENABLED;
			break;

		case E_SPI1_SDCARD_READ_ERROR:
			read8 = SPI1BUF;
			CS_SD = CS_LINE_UP;
			SPI1_release();
			state = E_SPI1_SDCARD_READ_INIT;
			request_template(TEMPLATE_SD_ERROR);
			SPI1Fbits.SD_r = 0;
			break;

		case E_SPI1_SDCARD_READ_LAST_FF:
			read8 = SPI1BUF;
			state = E_SPI1_SDCARD_READ_INIT;
			SPI1_release();
			SD_rw_index = 0;
			SPI1Fbits.SD_r = 0;
			if (SD_rw_callback != NULL)
				(*SD_rw_callback)();
			break;
	}

}


void	SD_read_block_callback(u32 src_block_address, u8 *dest, u16 length, generic_callback cb)
{
	SD_rw_length = length;
	SD_rw_index = 0;
	SD_rw_ptr = dest;
	SD_block_number = src_block_address;
	SD_rw_callback = cb;
	SPI1Fbits.SD_r = 1;
}

//u8	SD_card_read_block(u32 block_address, generic_callback cb)
//{
//	SD_rw_callback = cb;
//	SPI1Fbits.SD_r = 1;
//	SD_block_number = block_address;
//}
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

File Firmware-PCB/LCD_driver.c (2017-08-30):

#include <xc.h>
#include <sys/attribs.h>
#include "0x2a002a.h"

extern struct s_all	all;

static u32			SPI_LCD_count = 0;
static u16			SPI_buf_LCD[LCD_BUF_MAX] = { 0 };
static u32			SPI_LCD_index = 0;
static u8			lcd_changed_chars[8][CHARS_PER_LINE] = { 0 };
static u8			lcd_line_ptr = 0;
static u8			lcd_col_ptr = 1;
static u8			lcd_current_side = LCD_LEFT;

const u8	charset[][6] =
{
	{0x00, 0x00, 0x00, 0x00, 0x00, 0x00},
	{0x00, 0x00, 0x00, 0x00, 0x00, 0x00},
	{0x00, 0x00, 0x00, 0x00, 0x00, 0x00},
	{0x00, 0x00, 0x00, 0x00, 0x00, 0x00},
	{0x00, 0x00, 0x00, 0x00, 0x00, 0x00},
	{0x00, 0x00, 0x00, 0x00, 0x00, 0x00},
	{0x00, 0x00, 0x00, 0x00, 0x00, 0x00},
	{0x00, 0x00, 0x00, 0x00, 0x00, 0x00},
	{0x00, 0x00, 0x00, 0x00, 0x00, 0x00},
	{0x00, 0x00, 0x00, 0x00, 0x00, 0x00},
	{0x00, 0x00, 0x00, 0x00, 0x00, 0x00},
	{0x00, 0x00, 0x00, 0x00, 0x00, 0x00},
	{0x00, 0x00, 0x00, 0x00, 0x00, 0x00},
	{0x00, 0x00, 0x00, 0x00, 0x00, 0x00},
	{0x00, 0x00, 0x00, 0x00, 0x00, 0x00},
	{0x00, 0x00, 0x00, 0x00, 0x00, 0x00},
	{0x00, 0x00, 0x00, 0x00, 0x00, 0x00},
	{0x00, 0x00, 0x00, 0x00, 0x00, 0x00},
	{0x00, 0x00, 0x00, 0x00, 0x00, 0x00},
	{0x00, 0x00, 0x00, 0x00, 0x00, 0x00},
	{0x00, 0x00, 0x00, 0x00, 0x00, 0x00},
	{0x00, 0x00, 0x00, 0x00, 0x00, 0x00},
	{0x00, 0x00, 0x00, 0x00, 0x00, 0x00},
	{0x00, 0x00, 0x00, 0x00, 0x00, 0x00},
	{0x00, 0x00, 0x00, 0x00, 0x00, 0x00},
	{0x00, 0x00, 0x00, 0x00, 0x00, 0x00},
	{0x00, 0x00, 0x00, 0x00, 0x00, 0x00},
	{0x00, 0x00, 0x00, 0x00, 0x00, 0x00},
	{0x00, 0x00, 0x00, 0x00, 0x00, 0x00},
	{0x00, 0x00, 0x00, 0x00, 0x00, 0x00},
	{0x00, 0x00, 0x00, 0x00, 0x00, 0x00},
	{0x00, 0x00, 0x00, 0x00, 0x00, 0x00},
	{0x00, 0x00, 0x00, 0x00, 0x00, 0x00},
	{0x00, 0x00, 0x00, 0x5F, 0x00, 0x00},
	{0x00, 0x00, 0x07, 0x00, 0x07, 0x00},
	{0x00, 0x14, 0x7F, 0x14, 0x7F, 0x14},
	{0x00, 0x24, 0x2A, 0x7F, 0x2A, 0x12},
	{0x00, 0x23, 0x13, 0x08, 0x64, 0x62},
	{0x00, 0x36, 0x49, 0x55, 0x22, 0x50},
	{0x00, 0x00, 0x05, 0x03, 0x00, 0x00},
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
};


void	MCP_LCD_init(void)
{
	u16	read;

	SPI1CONbits.MODE16 = 1;

	//pins en output
	CS_MCP_LCD = 0x0;
	SPI1BUF = 0x4000;
	while (SPI1STATbits.SPIBUSY) ;
	read = SPI1BUF;
	SPI1BUF = 0x0000;
	while (SPI1STATbits.SPIBUSY) ;
	read = SPI1BUF;
	CS_MCP_LCD = 0x1;


	//mode sequentiel off
	CS_MCP_LCD = 0x0;
	SPI1BUF = 0x400A;
	while (SPI1STATbits.SPIBUSY) ;
	read = SPI1BUF;
	SPI1BUF = 0x2020;
	while (SPI1STATbits.SPIBUSY) ;
	read = SPI1BUF;
	CS_MCP_LCD = 0x1;

	SPI1CONbits.MODE16 = 0;
}


void	LCD_blocking_control_instruction(u8 cs1, u8 cs2, u8 di, u8 rw, u8 data)
{
	u16	send;
	u16	clear;

	send = (LCD_ENABLE_BIT | (rw != 0) * LCD_RW_BIT | (cs1 != 0) * LCD_CS1_bit | (cs2 != 0) * LCD_CS2_bit | (di != 0) * LCD_DI_BIT) << 8 | data;
	SPI1BUF = send;
	while (!SPI1STATbits.SPIRBF) ;
	clear = SPI1BUF;
	SPI1BUF = send & ~(LCD_ENABLE_BIT << 8);
	while (!SPI1STATbits.SPIRBF) ;
	clear = SPI1BUF;
}

void	LCD_init(void)
{
	u8	line = 0;
	u8	col;
	u16	clear;

	// clear du LCD
	CS_MCP_LCD = 0x0;
	SPI1CONbits.MODE16 = 1;
	SPI1BUF = 0x4012;
	while (SPI1STATbits.SPIBUSY) ;
	clear = SPI1BUF;
	LCD_blocking_control_instruction(1, 1, 0, 0, 0b00111111); // LCD_display_on_off(1);
	LCD_blocking_control_instruction(1, 1, 0, 0, 0b11000000); // LCD_display_start_origin(0);
	while (line < 8)
	{
		LCD_blocking_control_instruction(1, 1, 0, 0, 0b10111000 | line++); // LCD_display_set_x_page;
		col = 0;
		LCD_blocking_control_instruction(1, 1, 0, 0, 0b01000000 | col); // LCD_display_set_y_address(0);
		while (col++ < 64)
			LCD_blocking_control_instruction(1, 1, 1, 0, 0);
	}
	LCD_blocking_control_instruction(1, 1, 0, 0, 0b01000001); // LCD_display_set_y_address(1);
	LCD_blocking_control_instruction(1, 1, 0, 0, 0b10111000); // LCD_display_set_x_page(0);
	SPI1CONbits.MODE16 = 0;
	CS_MCP_LCD = 0x1;
}

u16	LCD_instruction_to_enable_low(u8 cs1, u8 cs2, u8 di, u8 rw, u8 data)
{
	return (((rw != 0) * LCD_RW_BIT | (cs1 != 0) * LCD_CS1_bit | (cs2 != 0) * LCD_CS2_bit | (di != 0) * LCD_DI_BIT) << 8 | data);
}


u16	LCD_display_start_origin(u8 side, u8 line)
{
	return (LCD_instruction_to_enable_low((side == LCD_LEFT), (side == LCD_RIGHT), 0, 0, 0xC0 | (line & 0x3F)));
}

u16 LCD_display_set_y_address(u8 side, u8 y)
{
	return (LCD_instruction_to_enable_low((side == LCD_LEFT), (side == LCD_RIGHT), 0, 0, 0x40 | (y & 0x3F)));
}

u16	LCD_display_set_x_page(u8 side, u8 x)
{
	return (LCD_instruction_to_enable_low((side == LCD_LEFT), (side == LCD_RIGHT), 0, 0, 0xB8 | (x & 0x7)));
}

u16	LCD_display_write_data(u8 side, u8 data)
{
	return (LCD_instruction_to_enable_low((side == LCD_LEFT), (side == LCD_RIGHT), 1, 0, data));
}

void	SPI1_push_LCD_buffer(u16 *buffer, u32 size)
{
	u32	i;

	IEC1bits.SPI1RXIE = 0;
	IEC1bits.SPI1TXIE = 0;
	i = 0;
	while (i < size)
		SPI_buf_LCD[SPI_LCD_count++] = buffer[i++];
	IEC1bits.SPI1RXIE = 1;
	IEC1bits.SPI1TXIE = 1;
}

void	LCD_print_u8(u8 line, u8 col, u8 data)
{
	u16	buffer[3] = { 0 };
	u8	index = 0;

	if ((col < 64 && lcd_current_side == LCD_RIGHT) || (col >= 64 && lcd_current_side == LCD_LEFT))
	{
		lcd_current_side = (col < 64) ? LCD_LEFT : LCD_RIGHT;
		buffer[index++] = LCD_display_set_x_page(lcd_current_side, line);
		buffer[index++] = LCD_display_set_y_address(lcd_current_side, col & 63);
		buffer[index++] = LCD_display_write_data(lcd_current_side, data);
		lcd_line_ptr = line;
		lcd_col_ptr = ++col & 63;
	}
	else if (line != lcd_line_ptr)
	{
		buffer[index++] = LCD_display_set_x_page(lcd_current_side, line);
		buffer[index++] = LCD_display_set_y_address(lcd_current_side, col & 63);
		buffer[index++] = LCD_display_write_data(lcd_current_side, data);
		lcd_line_ptr = line;
		lcd_col_ptr = ++col & 63;
	}
	else if (col != lcd_col_ptr)
	{
		buffer[index++] = LCD_display_set_y_address(lcd_current_side, col & 63);
		buffer[index++] = LCD_display_write_data(lcd_current_side, data);
		lcd_col_ptr = ++col & 63;
	}
	else
	{
		buffer[index++] = LCD_display_write_data(lcd_current_side, data);
		lcd_col_ptr = ++col & 63;
	}
	SPI1_push_LCD_buffer(buffer, index);
}

void	LCD_print_char(u8 line, u8 pos, u8 c)
{
	u8	i = 0;

	if (line > 8 || pos > CHARS_PER_LINE)
		return ;
	pos = 6 * pos + 1;
	while (i < 6)
		LCD_print_u8(line, pos++, (c < 128) ? charset[c][i++] : ~(charset[c - 128][i++]));
	// si le caractere est superieur a 127, alors c'est la "diapositive" de l'autre
	// peut etre avantageux de modifier le charset directement ...
}

void	LCD_print_changed_chars(void)
{
	u8	line = 0;
	u8	pos;

	while (line < 8)
	{
		pos = 0;
		while (pos < CHARS_PER_LINE)
		{
			if (lcd_changed_chars[line][pos])
			{
				lcd_changed_chars[line][pos] = 0;
				LCD_print_char(line, pos, all.lcd_chars[line][pos]);
			}
			++pos;
		}
		++line;
	}
}

void	LCD_putchar(u8 line, u8 pos, u8 c)
{
	if (all.lcd_chars[line][pos] != c)
	{
		all.lcd_chars[line][pos] = c;
		lcd_changed_chars[line][pos] = 1;
	}
}

void	LCD_clear(void)
{
	u8	line = 0;
	u8	pos = 0;

	while (line < 8)
	{
		pos = 0;
		while (pos < CHARS_PER_LINE)
			LCD_putchar(line, pos++, ' ');
		line++;
	}
}
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

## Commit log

2017-05-06 Mise en place du GIT
    [0-main.SchDoc, 0x2a002a.PcbLib, 0x2a002a.PrjPcb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]
2017-05-08 Chenillard ok i2c valide
2017-05-09 fix read interrupt on ack sequence
    [I2C.c, init.c]
2017-05-12 I2C done, long pressed button ok, clean des fichier a finir proprement
2017-05-12 I2C done, long pressed button ok, clean des fichier a finir proprement ... woops + comments
2017-05-15 Refactor I2C2 (#1)
    * modifs Theof
    * removed hidden files and software interrupts
    * changed I2C2 functions to allow callbacks
    * corrige pb de reinitialisation
    [0x2a002a.h, HT16_keys_driver.c, I2C_driver.c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]
2017-05-15 encodeur general valide: changt LED du HT16
2017-05-24 Mcp (#2)
    * les change notifs ne partent pas encore correctement
    * Un debut de SPI ... encodeur general ok en interrupt
    * init SPI before enabling timer
    * SPI renvoie des trucs chelou en retour
    * attempting blocking read
    * SPI2 OK en blocant, faire interrupt, logique des encodeurs a suivre suivant mes commentaires, Bisous
    * le ks01708 cést chiant
    * LCD ok via MCP, mise au propre a faire, Bisous
    * Revision Schema done, restes quelques footprints a faire...
    * sd footprint, pin num not done
    * before merge
    [0-main.SchDoc, 0x2a002a.PcbLib, 0x2a002a.PrjPcb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]
2017-05-31 Pcb (#3)
    * fixed cods
    * placement des compos
    * placement des compos
    * pcb en cours ...
    * Pcd en cours 2 ... ht16 a cable
    * pcb almost done ... reste opti et verif a faire
    * Mon PCB est plus beau que celui de Maxime
    * je pinaille ... almost ready to verif
    * Done ... verification en cours
    * v0 OK haha ... a demain
    * Verifs PCB en cours
    * reste capa tantale chimique et res diode a referencer
    * verif bom ok reste a refaire les calculs pour le 5v
    * ok ... reste a faire les outputs jobs ... bisous
    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
    [0-main.SchDoc, 0x2a002a.PcbLib, 0x2a002a.PrjPcb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]
2017-05-31 Refactor + ft_pustr on lcd
    [Bill of Materials-0x2a002a.xlsx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]
2017-06-01 state machine spi a finir
2017-06-06 Pistes 5V 1mm, pistes 3V 0.7mm, pastilles encodeurs plus grandes, WIP:via 0.7mm
    [0-main.SchDoc, 0x2a002a.PcbLib, 9-LCD.SchDoc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]
2017-06-06 Masse ok, reste MOSI MISO
    [0-main.SchDoc, 0x2a002a.PcbLib, 0x2a002a.PrjPcb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]
2017-06-07 miso ok
    [4-Memorie.SchDoc, PCB1.PcbDoc]
2017-06-07 alignement 5v
    [PCB1.PcbDoc]
2017-06-07 Dossier de fabrication
    [0x2a002a.PrjPcb, Bill of Materials-0x2a002a.xlsx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]
2017-06-12 merge refactor (#4) (#5)
    * Pistes 5V 1mm, pistes 3V 0.7mm, pastilles encodeurs plus grandes, WIP:via 0.7mm
    * Masse ok, reste MOSI MISO
    * miso ok
    * Peaufinage
    * alignement 5v
    * Dossier de fabrication
2017-06-12 spi driver working
2017-06-20 SPI + Cleaning (#7)
    * mode sequentiel OK
    * marche en non bloquant
    * driver lcd quasi pret
    * putstr marche sa mere git add -A!
    * cleaning
    [0-main.SchDoc, 0x2a002a.PcbLib, 0x2a002a.PrjPcb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]
2017-07-03 Revamp (#8)
    * read write flash ok en blocant
    * defines des instrus
    * One encoder through mcp
    * interrupts fonctionnent 1 encodeur
    * gauche droite OK avec des while dedans
    * 1 encoder SPI full interrupt
    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
    [0x2a002a.PrjPcb, PCB1.PcbDoc, bom_complementaire.xlsx]
2017-07-04 eeprom en debut de kaldjfnbvsdfb
2017-07-04 split timers and prescale timer 2
2017-07-04 new timers and bpm management
2017-07-04 better tests to try for spi
2017-07-04 SD marche en mode bloquant + fix UART
    [0x2a002a.h, LCD_templates.c, SPI_driver.c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]
2017-07-04 fixed HT16 state machine
    [I2C_driver.c, UART_driver.c, input_handler.c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]
2017-07-05 fixed HT16. changed bpm to float
    [input_handler.c, main.c, timer.c]
2017-07-05 debut de mechanisme machine
2017-07-05 templates + data structure + changement timer
2017-07-05 fonctionnement de base OK
2017-07-06 put inits in each section except timers
2017-07-06 changed encoders priority
2017-07-06 changed display logic to fix LCD buffer that overflowed
    [LCD_driver.c, LCD_templates.c, SPI_driver.c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]
2017-07-06 put timer related inits in respective folders
2017-07-06 fixed tap bpm that was conficting with encoder
    [input_handler.c]
2017-07-06 moved LEDs logic to the output handler file
2017-07-06 il faut regler les encodeurs en mouvement rapide
2017-07-06 raised mcp enc int priority and fixed timing deadlock
    [encoders_driver.c, input_handler.c]
2017-07-07 prescale encoder values for MIDI
2017-07-07 encoders midi mapped
2017-07-07 encoders click to change octave display notes names
2017-07-07 fixed minor bug in the play / pause logic
    [input_handler.c]
2017-07-08 removed extra I2C config
2017-07-08 update I2C driver with persistent interrupts
2017-07-08 defined NO_NOTE to fix the problem with otave 0 (note was zero)
    [0x2a002a.h, input_handler.c, main.c]
2017-07-08 changed logic for templates - display bug but was there before
    [LCD_templates.c, SPI_driver.c, input_handler.c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]
2017-07-10 sapin de noel keyboard
2017-07-10 fixed HT16 read request
    [EEPROM_driver.c, HT16_keys_driver.c, input_handler.c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]
2017-07-12 changed HT16 logic to polling after first interrupt
2017-07-12 fixed bpm input and long press limit
    [HT16_keys_driver.c, I2C_driver.c, input_handler.c]
2017-07-12 rattrape mais toujours bugge
    [0x2a002a.h, EEPROM_driver.c, ENCODERS.h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]
2017-07-12 cleaned the LEDs display functions
2017-07-13 added some button logic (edit pattern etc)
2017-07-14 timer 4 turned into generic callback timer
    changed the commiter name
2017-07-16 added the slot adding of notes
2017-07-16 correctd minor bug on multi adding
    [input_handler.c]
2017-07-16 comportement etrange sur presence de carte sd
2017-07-17 fixed menu bug + added copy paste and erase options
    [EEPROM_driver.c, LCD_templates.c, input_handler.c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]
2017-07-17 fixed long notes muting other notes
    [input_handler.c]
2017-07-17 remove midi_ppqn and fixed keyboard polyphony notes not going off.
    [0x2a002a.h, input_handler.c]
2017-07-18 fix midi race conditions
    [UART_driver.c]
2017-07-20 seems like eeprom loading is no problem anymore
    [main.c]
2017-07-20 fix UART buffer overflow
    [UART_driver.c]
2017-07-21 keyboard notes display fixed on NO_NOTE input
    [LCD_templates.c]
2017-07-23 fixed rec keyboard midi channel hardcoded
    [input_handler.c]
2017-07-25 fixed UART bug bad int flag clearing
2017-07-27 main encoder fixed
2017-07-28 added SD error if removed
    [SDCARD_driver.c]
2017-07-31 Midi enhancements (#10)
    * add support for UART idle callback.
    * enhanced UART callback
    * notes off on play/pause and instrument muted
    * encoders have less priority on midi than step notes
    * quick fix for switching between instruments correctly
    * generate notes off when switching patterns
    * mute instruments done
    * remove extra line
    [EEPROM_driver.c, MIDI.h, UART_driver.c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]
2017-07-31 revert encoders to prevent lcd display bug
    [UART_driver.c, input_handler.c, main.c]
2017-08-09 fixed midi when switching between instruments
    [EEPROM_driver.c, input_handler.c]
2017-08-16 instrument change now arrives on the right current pattern
2017-08-29 added all bugs and corrections form new master, now time to speed it up
    [ENCODERS.h, LCD_driver.c, LCD_templates.c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]
2017-08-30 changed most global variables to either static of global struct, I2C driver and HT16 remains tbd
